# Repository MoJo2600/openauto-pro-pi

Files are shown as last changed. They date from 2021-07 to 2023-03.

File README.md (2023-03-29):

# Automotive power hat for OpenAuto

This hat is designed to work together with OpenAuto Pro and deliver some functionality which makes integrating OpenAuto into your car easier.

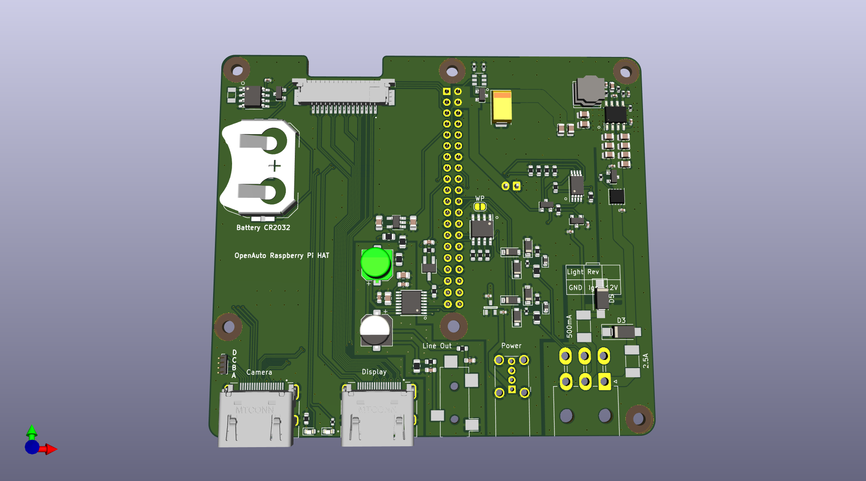
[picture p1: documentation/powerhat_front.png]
front


## Work in progress - a word of warning

I'm not an electronics professional and this board is currently work in progress. If somebody is willing to do a indepth review with me I would be very glad. Reach out to me on twitter [@MoJo2600](https://twitter.com/MoJo2600).

## Features

* Integrated 5A Power Supply
* Wide range power input (+7.5V to +40V)
* On-/Off circuit with ignition sensing
* 2 Digital inputs for e.g. reverse signal
* I2S sound
* RTC clock
* CSI to HDMI adapters to connect a display and camera
  * I2C bus availabe on the display connector for a light sensor
* Designed to fit exactly onto a [Geekworm x825](https://wiki.geekworm.com/index.php/X825) SSD V1 (Not tested with V2 but should fit)

## Connections
the following pins are used on the pi.

|Connection | Pin |
|---|-----|
|I2C |BCM23|
|I2C |BCM24|
|REVERSE |BCM8 |
|LIGHT |BCM25|
|PI UP |BCM23|
|SHUTDOWN |BCM24|
|I2S DAC MUTE |BCM16|
|I2S DAC BITCLK |BCM18|
|I2S DAC LRCLK  |BCM19|
|I2S DAC DATAIN |BCM21|

## OpenAuto Pro Setup

Set up the device before you add the header to the raspberry pi. The device will constantly reboot if the Start / Stop script is not installed. An alternative is to bridge the 3.3V pin from the raspberry pi to BCM23.

### Start / Stop script

Copy `scripts/startstop.sh` to the openauto device.

`sudo bash startstop.sh`

### I2C Real Time Clock

Make sure the battery has contact to the pad on the minus size. Mine had not and I added a little bit of solder to the pad to make contact.

```
# select pcf85063
```

### Rearview camera script

This script will open raspivid and show the picture of the rear camera.

Copy all files to the raspberry pi and start the setup

`./setup.sh`

### Brightness control script

My brightness script utilizes the TSL2561 ambient light sensor. The script implements a recommendation from analog devices
https://www.analog.com/en/design-notes/a-simple-implementation-of-lcd-brightness-control-using-the-max44009-ambientlight-sensor.html

Copy all files to the raspberry pi and start the setup

`./setup.sh`

### Audio output

The current audio circuit is not really usable. The output is very noisy und the signal is too low to usw it effectively. If you want to try i t you can use the following settings.

Add the overlays to `/boot/config.txt`

```
dtoverlay=hifiberry-dac
dtoverlay=i2s-mmap
```

After a reboot the sound should be working. Expect a line level output. If the volume is set to high, there will be clipping.

## Fixes for Issues

### Bluetooth Dongle BCM20702A1 not working

I had to install the bluetooth firmware for my broadcom bluetooth dongle from this repository https://github.com/winterheart/broadcom-bt-firmware.

The error in dmesg was:

```
bluetooth hci1: Direct firmware load for brcm/BCM20702A1-0a5c-21e8 failed with error -2
Bluetooth: hci1: BCM: Patch brcm/BCM20702A1-0a5c-21e8 not found
```

The installation was easy:

```
wget https://github.com/winterheart/broadcom-bt-firmware/raw/master/brcm/BCM20702A1-0a5c-21e8.hcd
sudo cp *.hcd /lib/firmware/brcm/
```

## History

Here is a picture of prototype V1 with a Mouseberry power supply.

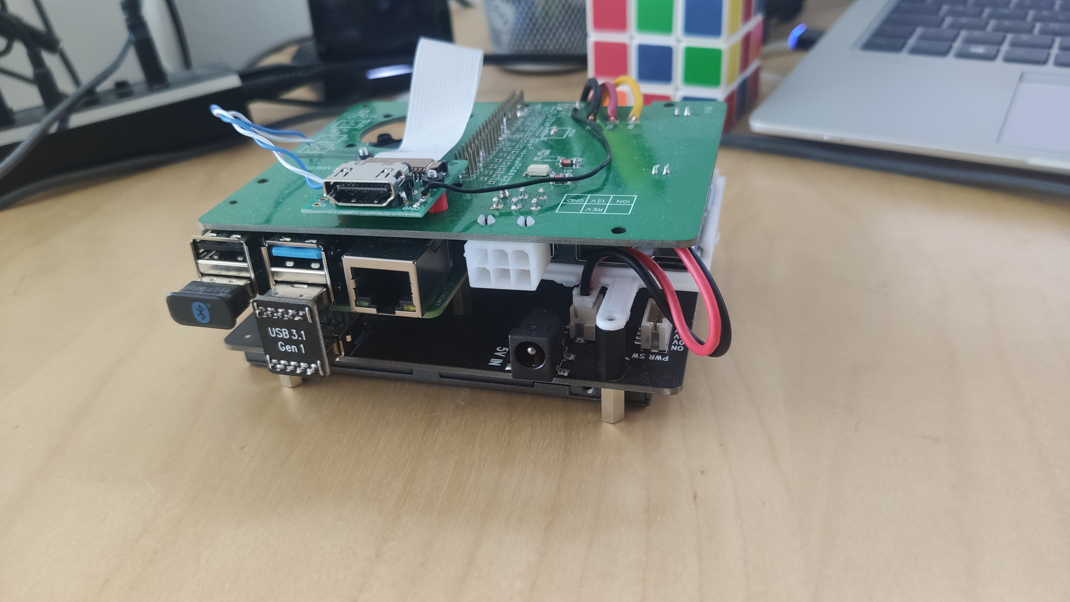
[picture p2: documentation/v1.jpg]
v1


## Disclaimer

Due to the fact we are not providing a product in the legal sense, we are also not providing any warranty in any aspect.

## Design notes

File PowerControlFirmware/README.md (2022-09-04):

# ATTINY firmware for power control

This firmeware controls the buck converter to power the PI. It waits for the PI to boot and signals the PI to shut down when the ignition is turned off.

## Pinout

## Implementation

## Flashing in WSL

Create udev rule for USBTiny to give regular users in `dialout` group rights to the device

```
echo 'SUBSYSTEM=="usb", ATTR{idProduct}=="0c9f", ATTR{idVendor}=="1781", MODE="0666", GROUP="dialout"' > /etc/udev/rules.d/99-USBTiny.rules
```

Restart the udev service

```
sudo service udev restart
sudo udevadm control --reload
```

Attach the USB device to the WSL

```
usbipd attach --bus-id X-Y
```

Flash your code

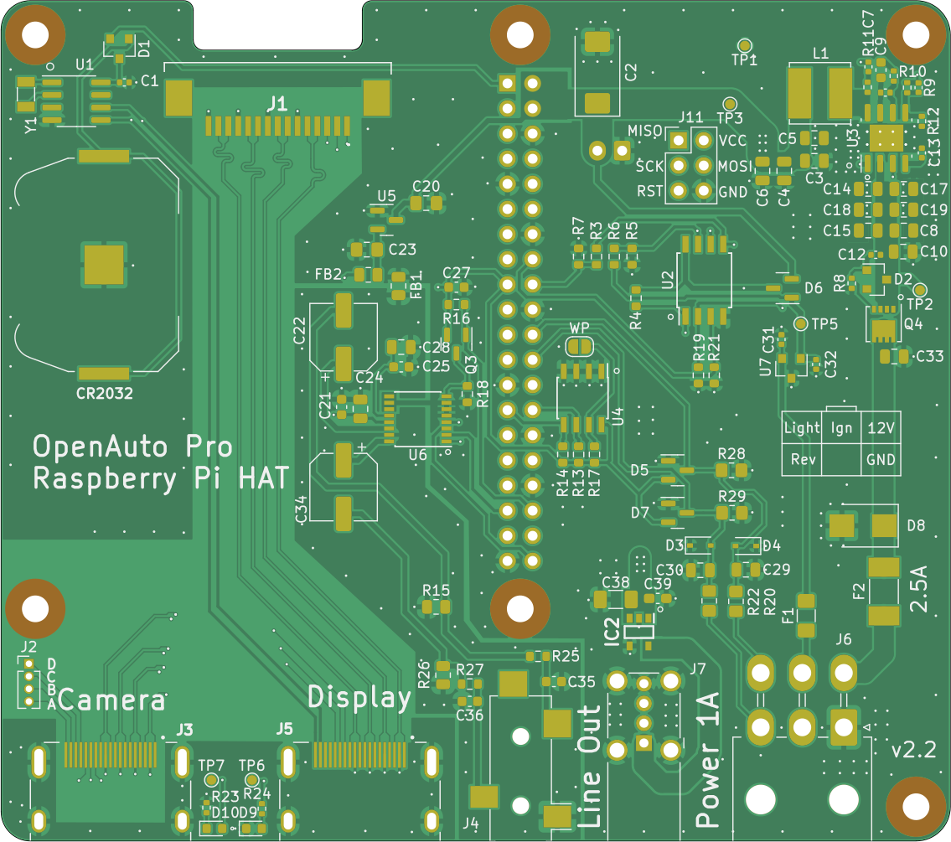
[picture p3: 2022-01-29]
CarPiPowerHat/foo.png

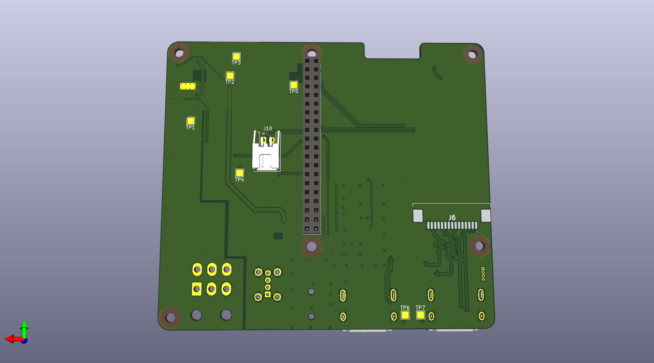
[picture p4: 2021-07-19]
documentation/powerhat_back.png

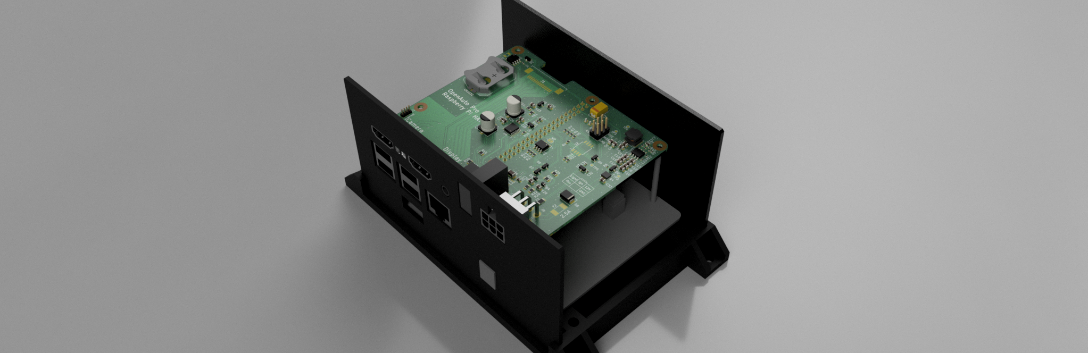
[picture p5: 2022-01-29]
CarPiPowerHat/prod/Raspberry Case V3 v27.png

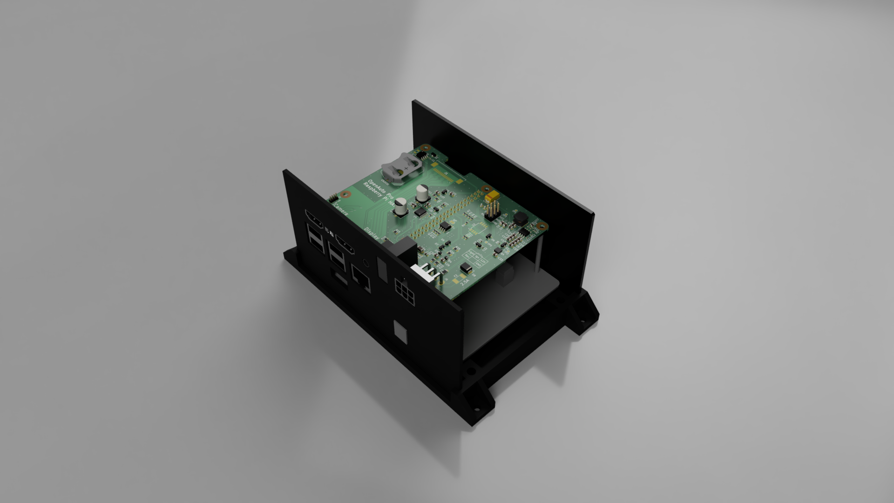
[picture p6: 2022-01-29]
CarPiPowerHat/prod/b1094724-6803-44ca-8cfa-f048102307d0.PNG

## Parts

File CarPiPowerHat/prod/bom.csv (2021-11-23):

Comment | Designator | Footprint | LCSC
1uF | C20,C23 | Capacitor_SMD:C_0805_2012Metric_Pad1.18x1.45mm_HandSolder | C28323
0.1uF | C21,C25,C27 | Capacitor_SMD:C_0603_1608Metric | C14663
47uF | C22,C34 | Capacitor_SMD:CP_Elec_6.3x7.7 | C164078
22nF | C29,C30 | Capacitor_SMD:C_0805_2012Metric | C1729
10uF | C3,C4,C5,C6,C24,C28 | Capacitor_SMD:C_0805_2012Metric | C15850
100n 100v | C33 | Capacitor_SMD:C_0805_2012Metric | C28233
0.01uF | C35,C36 | Capacitor_SMD:C_0603_1608Metric | C57112
100uF | C38 | Capacitor_SMD:C_1206_3216Metric_Pad1.33x1.80mm_HandSolder | C15008
1uF | C39 | Capacitor_SMD:C_0603_1608Metric_Pad1.08x0.95mm_HandSolder | C15849
100n 16v | C1,C7,C12,C13,C31,C32 | Capacitor_SMD:C_0402_1005Metric | C1525
10uF 35v | C8,C10,C14,C15,C17,C18,C19 | Capacitor_SMD:C_0805_2012Metric | C440198
1.2nF | C9 | Capacitor_SMD:C_0603_1608Metric | C30615
LED Green | D10 | LED_SMD:LED_0603_1608Metric | C72043
MMBZ5242BLT3G | D2 | Diode_SMD:D_SOT-23_ANK | C268585
PESD12VL1BA-N | D3,D4 | Diode_SMD:D_SOD-323 | C314261
BAT54S | D5,D7 | Package_TO_SOT_SMD:SOT-23 | C408389
BAT54C-7-F | D1,D6 | Package_TO_SOT_SMD:SOT-23 | C37704
SMBJ33A | D8 | Diode_SMD:D_SMB | C353366
LED Blue | D9 | LED_SMD:LED_0603_1608Metric | C72041
Fuse | F1 | Fuse:Fuse_1206_3216Metric_Pad1.42x1.75mm_HandSolder | C206984
Ferrite | FB1,FB2 | Resistor_SMD:R_0805_2012Metric | C1017
BD2226G-TR | IC2 | SamacSys_Parts:SOT95P280X125-5N | C308587
DMG2305 | Q3 | Package_TO_SOT_SMD:SOT-23 | C144153
DMP3013SFV-7 | Q4 | Package_SON:Diodes_PowerDI3333-8 | C264098
20K 1% | R10 | Resistor_SMD:R_0402_1005Metric | C25765
10R | R11 | Resistor_SMD:R_0402_1005Metric | C25077
2.2K 1% | R12 | Resistor_SMD:R_0402_1005Metric | C25879
3.9K | R13,R14 | Resistor_SMD:R_0603_1608Metric | C23018
220k | R15,R26 | Resistor_SMD:R_0805_2012Metric | C17521
10K | R16,R17,R18 | Resistor_SMD:R_0603_1608Metric | C25804
10k | R20,R22 | Resistor_SMD:R_0805_2012Metric_Pad1.20x1.40mm_HandSolder | C17414
200 1% | R23,R24 | Resistor_SMD:R_0402_1005Metric | C25087
100 | R25,R27 | Resistor_SMD:R_0603_1608Metric | C22775
1M | R28,R29 | Resistor_SMD:R_0805_2012Metric_Pad1.20x1.40mm_HandSolder | C17514
10K 1% | R3,R4,R5,R7,R19,R21 | Resistor_SMD:R_0603_1608Metric | C25804
3.3K 1% | R6 | Resistor_SMD:R_0603_1608Metric | C22978
12K 1% | R8,R9 | Resistor_SMD:R_0402_1005Metric | C25752
PCF85063AT/AAZ | U1 | Package_SO:SOIC-8_3.9x4.9mm_P1.27mm | C7440
ATtiny45V-20SU | U2 | Package_SO:SOIC-8W_5.3x5.3mm_P1.27mm | C62689
AP64501SP-13 | U3 | Package_SO:SOIC-8-1EP_3.9x4.9mm_P1.27mm_EP2.95x4.9mm_Mask2.71x3.4mm_ThermalVias | C2071517
CAT24C32 | U4 | Package_SOIC:SOIC-8_3.9x4.9mm_P1.27mm | C81193
XC6206P332MR | U5 | Package_TO_SOT_SMD:SOT-23 | C5446
UDA1334ATS | U6 | Package_SO:SSOP-16_4.4x5.2mm_P0.65mm | C494494
LM3480-5.0 | U7 | Package_TO_SOT_SMD:SOT-23 | C129960
FC-12M32.768KHZ7PF20PPM | Y1 | Crystal:Crystal_SMD_3215-2Pin_3.2x1.5mm | C99009

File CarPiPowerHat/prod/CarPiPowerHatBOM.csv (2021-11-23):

Comment | Designator | Footprint | LCSC
Battery_Cell | BT1 | Battery:BatteryHolder_Keystone_3034_1x20mm
nf | C11,C16 | Capacitor_SMD:C_0402_1005Metric
100uF | C2 | Capacitor_Tantalum_SMD:CP_EIA-7343-31_Kemet-D
1uF | C20,C23 | Capacitor_SMD:C_0805_2012Metric_Pad1.18x1.45mm_HandSolder | C28323
0.1uF | C21,C25,C27 | Capacitor_SMD:C_0603_1608Metric | C14663
47uF | C22,C34 | Capacitor_SMD:CP_Elec_6.3x7.7 | C164078
22nF | C29,C30 | Capacitor_SMD:C_0805_2012Metric | C1729
10uF | C3,C4,C5,C6,C24,C28 | Capacitor_SMD:C_0805_2012Metric | C15850
100n 100v | C33 | Capacitor_SMD:C_0805_2012Metric | C28233
0.01uF | C35,C36 | Capacitor_SMD:C_0603_1608Metric | C57112
100uF | C38 | Capacitor_SMD:C_1206_3216Metric_Pad1.33x1.80mm_HandSolder | C15008
1uF | C39 | Capacitor_SMD:C_0603_1608Metric_Pad1.08x0.95mm_HandSolder | C15849
100n 16v | C1,C7,C12,C13,C31,C32 | Capacitor_SMD:C_0402_1005Metric | C1525
10uF 35v | C8,C10,C14,C15,C17,C18,C19 | Capacitor_SMD:C_0805_2012Metric | C440198
1.2nF | C9 | Capacitor_SMD:C_0603_1608Metric | C30615
LED Green | D10 | LED_SMD:LED_0603_1608Metric | C72043
MMBZ5242BLT3G | D2 | Diode_SMD:D_SOT-23_ANK | C268585
PESD12VL1BA-N | D3,D4 | Diode_SMD:D_SOD-323 | C314261
BAT54S | D5,D7 | Package_TO_SOT_SMD:SOT-23 | C408389
BAT54C-7-F | D1,D6 | Package_TO_SOT_SMD:SOT-23 | C37704
SMBJ33A | D8 | Diode_SMD:D_SMB | C353366
LED Blue | D9 | LED_SMD:LED_0603_1608Metric | C72041
Fuse | F1 | Fuse:Fuse_1206_3216Metric_Pad1.42x1.75mm_HandSolder | C206984
Fuse | F2 | Fuse:Fuse_Littelfuse-NANO2-451_453
Ferrite | FB1,FB2 | Resistor_SMD:R_0805_2012Metric | C1017
3mm_Mounting_Hole | H1,H2,H3,H4,H5,H6 | MountingHole:MountingHole_2.7mm_M2.5
BD2226G-TR | IC2 | SamacSys_Parts:SOT95P280X125-5N | C308587
1-84953-5 | J1,J10 | SamacSys_Parts:1849535
Conn_01x06_Male | J11 | Connector_PinHeader_2.54mm:PinHeader_2x03_P2.54mm_Vertical
Conn_01x04 | J2 | Connector_PinHeader_2.00mm:PinHeader_1x04_P2.00mm_Vertical
HDMI_A_1.4 | J3,J5 | project_footprints:EDAC 690-019-298-412
AudioJack2_Ground | J4 | Connector_Audio:Jack_3.5mm_CUI_SJ-3524-SMT_Horizontal
Conn_02x03_Counter_Clockwise | J6 | Connector_Molex:Molex_Mini-Fit_Jr_5569-06A2_2x03_P4.20mm_Horizontal
USB_A | J7 | Connector_USB:USB_A_Wuerth_614004134726_Horizontal
Conn_01x02_Male | J8 | Connector_JST:JST_XH_S2B-XH-A_1x02_P2.50mm_Horizontal
40HAT | J9 | Connector_PinSocket_2.54mm:PinSocket_2x20_P2.54mm_Vertical
SolderJumper_2_Open | JP1 | Jumper:SolderJumper-2_P1.3mm_Open_RoundedPad1.0x1.5mm
SRN6045TA-3R3Y | L1 | Inductor_SMD:L_Bourns_SRN6045TA
DMG2305 | Q3 | Package_TO_SOT_SMD:SOT-23 | C144153
DMP3013SFV-7 | Q4 | Package_SON:Diodes_PowerDI3333-8 | C264098
20K 1% | R10 | Resistor_SMD:R_0402_1005Metric | C25765
10R | R11 | Resistor_SMD:R_0402_1005Metric | C25077
2.2K 1% | R12 | Resistor_SMD:R_0402_1005Metric | C25879
3.9K | R13,R14 | Resistor_SMD:R_0603_1608Metric | C23018
220k | R15,R26 | Resistor_SMD:R_0805_2012Metric | C17521
10K | R16,R17,R18 | Resistor_SMD:R_0603_1608Metric | C25804
10k | R20,R22 | Resistor_SMD:R_0805_2012Metric_Pad1.20x1.40mm_HandSolder | C17414
200 1% | R23,R24 | Resistor_SMD:R_0402_1005Metric | C25087
100 | R25,R27 | Resistor_SMD:R_0603_1608Metric | C22775
1M | R28,R29 | Resistor_SMD:R_0805_2012Metric_Pad1.20x1.40mm_HandSolder | C17514
10K 1% | R3,R4,R5,R7,R19,R21 | Resistor_SMD:R_0603_1608Metric | C25804
3.3K 1% | R6 | Resistor_SMD:R_0603_1608Metric | C22978
12K 1% | R8,R9 | Resistor_SMD:R_0402_1005Metric | C25752
TestPoint | TP1,TP2,TP3,TP5,TP6,TP7 | TestPoint:TestPoint_Pad_D1.0mm
PCF85063AT/AAZ | U1 | Package_SO:SOIC-8_3.9x4.9mm_P1.27mm | C7440
ATtiny45V-20SU | U2 | Package_SO:SOIC-8W_5.3x5.3mm_P1.27mm | C62689
AP64501SP-13 | U3 | Package_SO:SOIC-8-1EP_3.9x4.9mm_P1.27mm_EP2.95x4.9mm_Mask2.71x3.4mm_ThermalVias | C2071517
CAT24C32 | U4 | Package_SOIC:SOIC-8_3.9x4.9mm_P1.27mm | C81193
XC6206P332MR | U5 | Package_TO_SOT_SMD:SOT-23 | C5446
UDA1334ATS | U6 | Package_SO:SSOP-16_4.4x5.2mm_P0.65mm | C494494
LM3480-5.0 | U7 | Package_TO_SOT_SMD:SOT-23 | C129960
FC-12M32.768KHZ7PF20PPM | Y1 | Crystal:Crystal_SMD_3215-2Pin_3.2x1.5mm | C99009

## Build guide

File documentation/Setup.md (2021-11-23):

# Initial Setup

!Do not power the Raspberry Pi from the USB-C port once you have the SSD attached
!Do not power the Raspberry Pi from the USB-C port when the HAT is attached

Before we attach the header we have to setup the

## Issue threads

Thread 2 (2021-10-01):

I2C decoder with UDA1334ATS is obsolete

MoJo2600, 2021-10-01:
The chip UDA1334ATS is not produced anymore, what I did not realize. So the audio circuit is obsolete. I don't know what a good replacement would be - Maybe WM8960 but this chip is not available on JLCPCB and hard to hand solder.

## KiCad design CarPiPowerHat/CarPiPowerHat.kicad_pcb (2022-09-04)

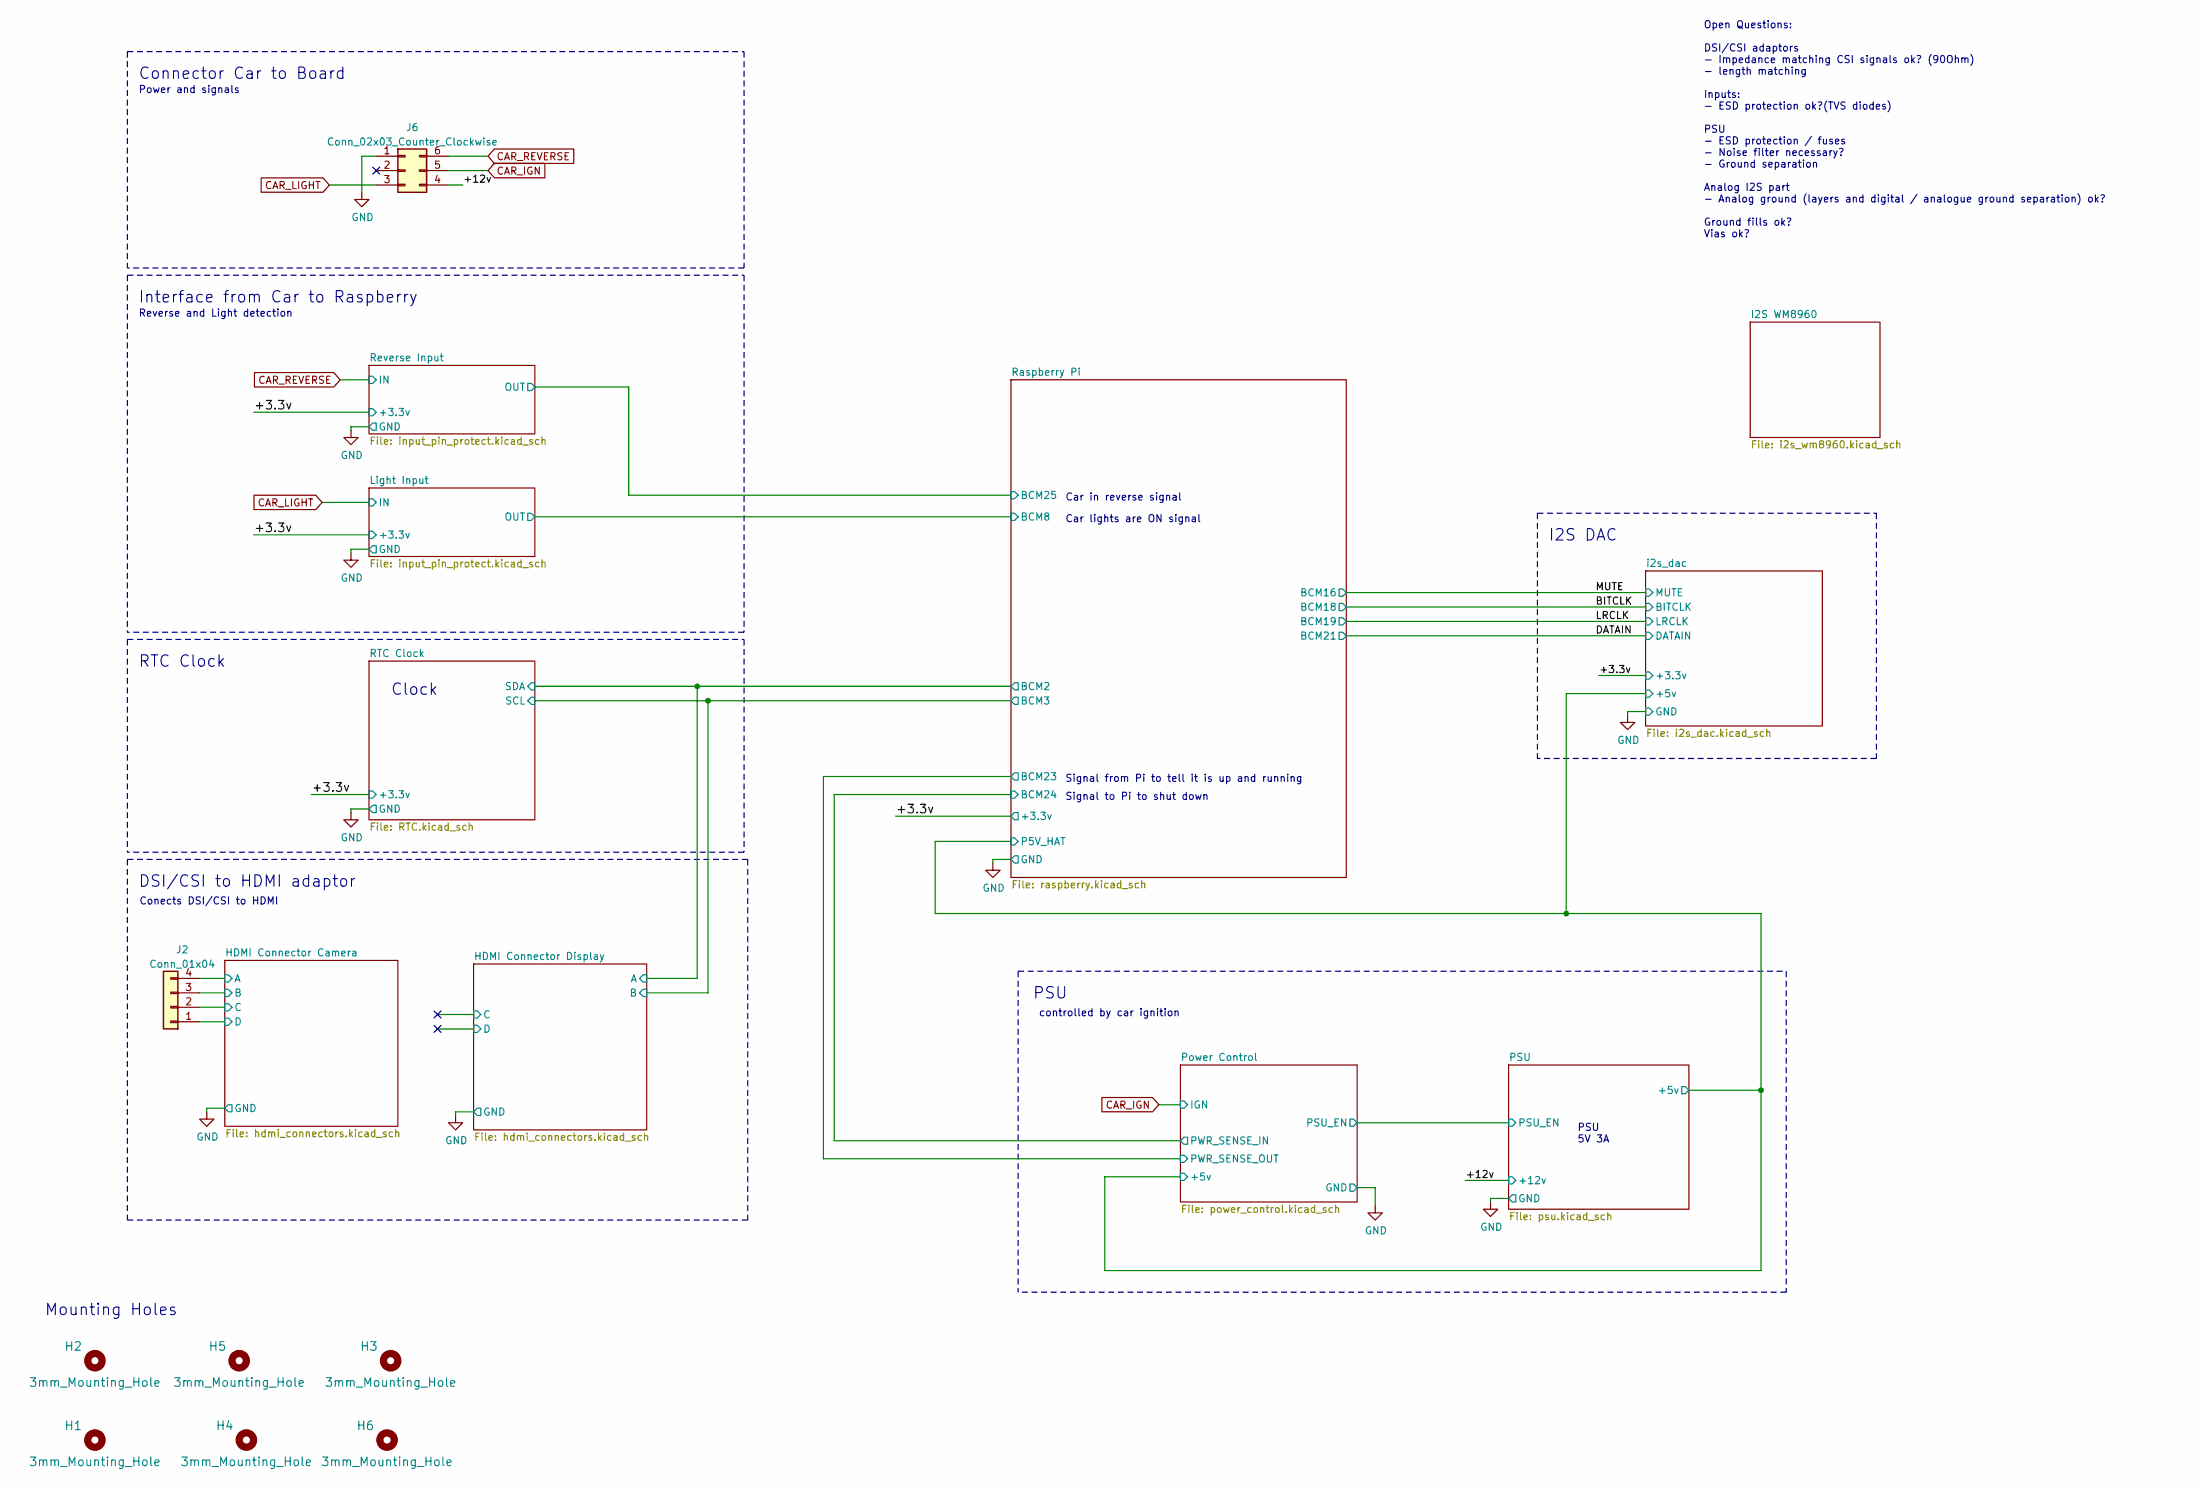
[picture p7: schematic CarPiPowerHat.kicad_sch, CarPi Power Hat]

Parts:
H1, H2, H3, H4, H5, H6: 3mm_Mounting_Hole; MountingHole_2.7mm_M2.5
J2: Conn_01x04; PinHeader_1x04_P2.00mm_Vertical
J6: Conn_02x03_Counter_Clockwise; Molex_Mini-Fit_Jr_5569-06A2_2x03_P4.20mm_Horizontal; MouserNr 538-50-36-1798

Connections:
/+12v: J6.4; also elsewhere on the board
/HDMI Connector Camera/A: J2.4; also elsewhere on the board
/HDMI Connector Camera/B: J2.3; also elsewhere on the board
/HDMI Connector Camera/C: J2.2; also elsewhere on the board
/HDMI Connector Camera/D: J2.1; also elsewhere on the board
CAR_IGN: J6.5; also elsewhere on the board
CAR_LIGHT: J6.3; also elsewhere on the board
CAR_REVERSE: J6.6; also elsewhere on the board
GND: J6.1; also elsewhere on the board

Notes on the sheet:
Open Questions: DSI/CSI adaptors - Impedance matching CSI signals ok? (90Ohm) - length matching Inputs: - ESD protection ok?(TVS diodes) PSU - ESD protection / fuses - Noise filter necessary? - Ground separation Analog I2S part - Analog ground (layers and digital / analogue ground separation) ok? G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
PSU 5V 3A
Mounting Holes
Power and signals
PSU
I2S DAC
RTC Clock
controlled by car ignition
Clock
Signal to Pi to shut down
Signal from Pi to tell it is up and running
Car lights are ON signal
Connector Car to Board
DSI/CSI to HDMI adaptor
Reverse and Light detection
Conects DSI/CSI to HDMI
Car in reverse signal
Interface from Car to Raspberry

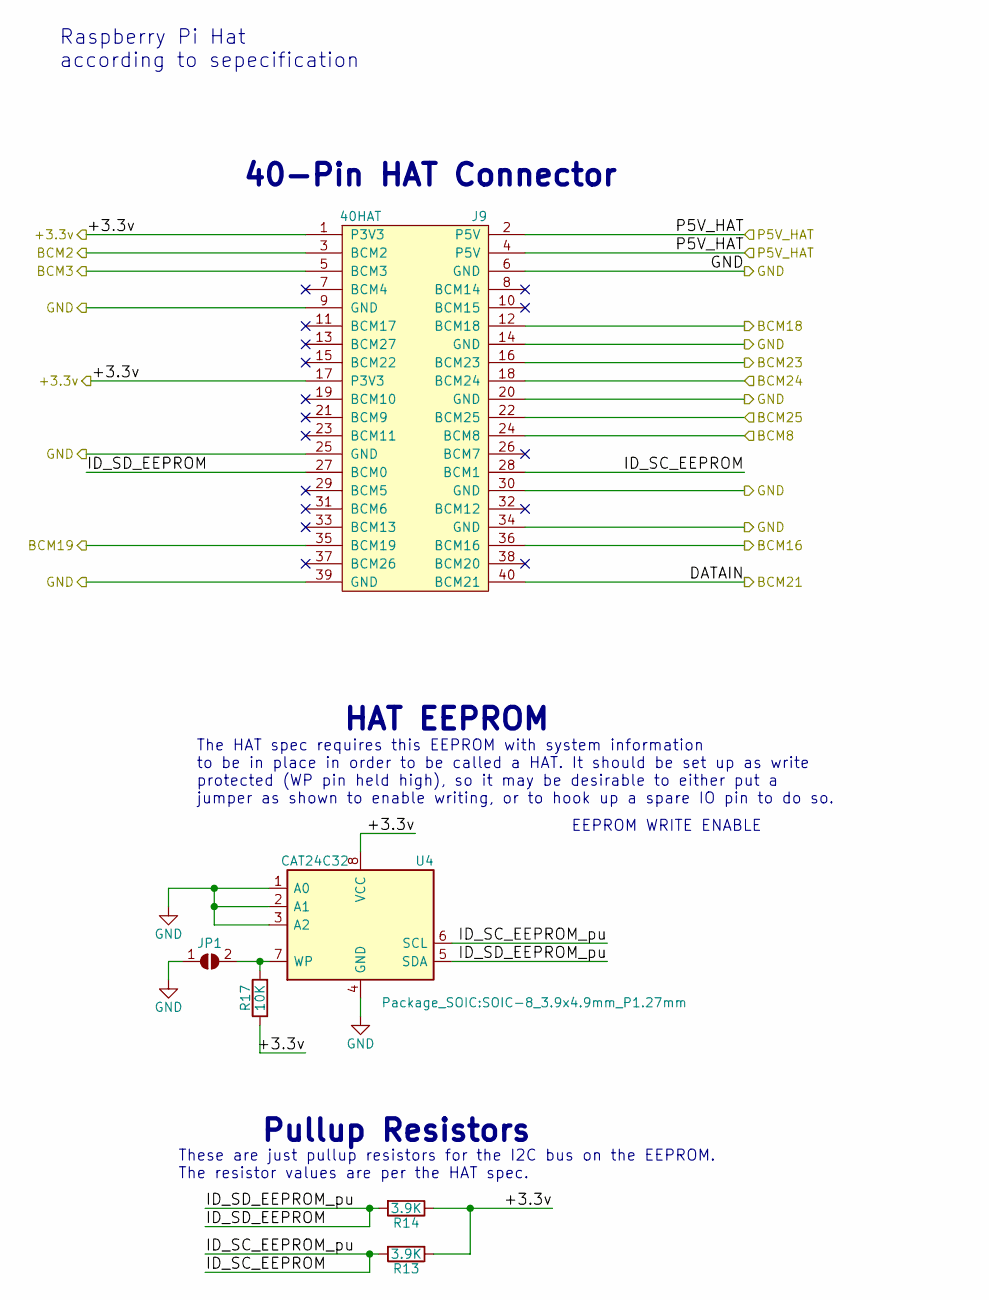
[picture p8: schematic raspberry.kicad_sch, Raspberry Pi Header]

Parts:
J9: 40HAT; PinSocket_2x20_P2.54mm_Vertical
JP1: SolderJumper_2_Open; SolderJumper-2_P1.3mm_Open_RoundedPad1.0x1.5mm
R13, R14: 3.9K; R_0603_1608Metric; LCSC C23018
R17: 10K; R_0603_1608Metric; LCSC C25804
U4: CAT24C32; SOIC-8_3.9x4.9mm_P1.27mm; LCSC C81193

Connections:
/+3.3v: J9.1 (P3V3), J9.17 (P3V3), R13.1, R14.1, R17.1, U4.8 (VCC); also elsewhere on the board
/BITCLK: J9.12 (BCM18); also elsewhere on the board
/DATAIN: J9.40 (BCM21); also elsewhere on the board
/LRCLK: J9.35 (BCM19); also elsewhere on the board
/Light Input/OUT: J9.24 (BCM8); also elsewhere on the board
/MUTE: J9.36 (BCM16); also elsewhere on the board
/Power Control/PWR_SENSE_IN: J9.18 (BCM24); also elsewhere on the board
/RTC Clock/SCL: J9.5 (BCM3); also elsewhere on the board
/RTC Clock/SDA: J9.3 (BCM2); also elsewhere on the board
/Raspberry Pi/BCM25: J9.22 (BCM25); also elsewhere on the board
/Raspberry Pi/ID_SC_EEPROM: J9.28 (BCM1), R13.2, U4.6 (SCL)
/Raspberry Pi/ID_SD_EEPROM: J9.27 (BCM0), R14.2, U4.5 (SDA)
/Raspberry Pi/P5V_HAT: J9.2 (P5V), J9.4 (P5V); also elsewhere on the board
GND: J9.6 (GND), J9.9 (GND), J9.14 (GND), J9.20 (GND), J9.25 (GND), J9.30 (GND), J9.34 (GND), J9.39 (GND), JP1.1 (A), U4.1 (A0), U4.2 (A1), U4.3 (A2), U4.4 (GND); also elsewhere on the board
unnamed: JP1.2 (B), R17.2, U4.7 (WP)
PWR_SENSE_OUT: J9.16 (BCM23); also elsewhere on the board

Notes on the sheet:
EEPROM WRITE ENABLE
Pullup Resistors
40-Pin HAT Connector
HAT EEPROM
The HAT spec requires this EEPROM with system information to be in place in order to be called a HAT. It should be set up as write protected (WP pin held high), so it may be desirable to either put a jumper as shown to enable writing, or to hook up a spare IO pin to do so.
Raspberry Pi Hat according to sepecification
These are just pullup resistors for the I2C bus on the EEPROM. The resistor values are per the HAT spec.

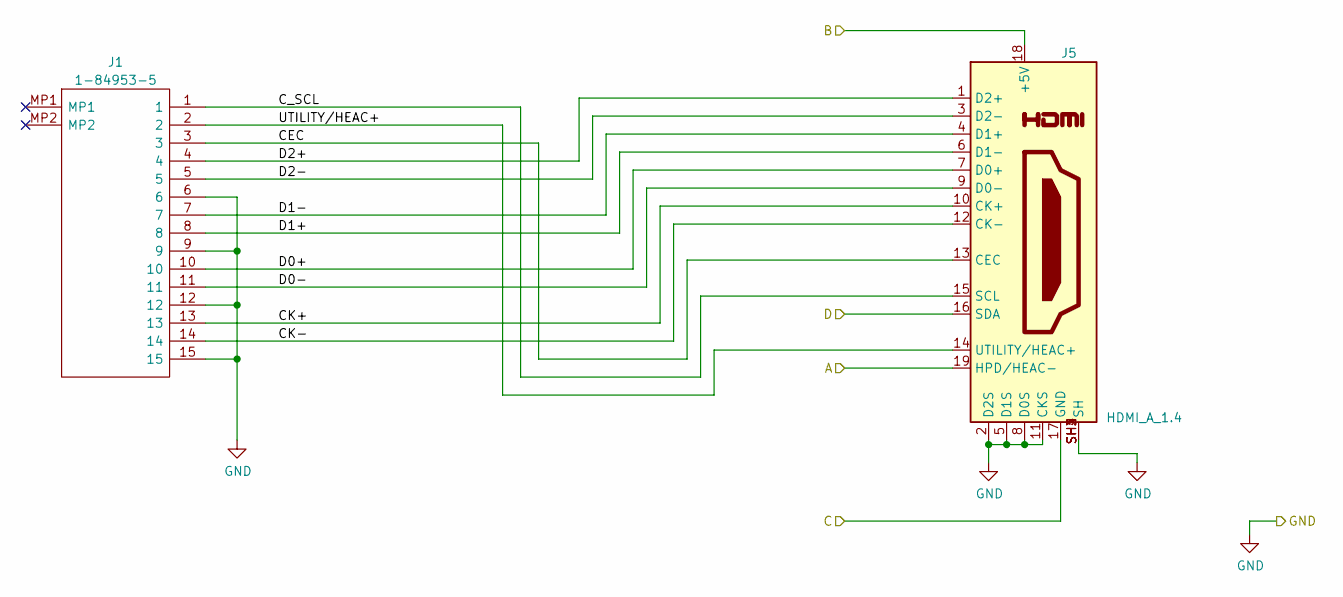
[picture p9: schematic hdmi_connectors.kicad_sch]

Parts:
J1: 1-84953-5; 1849535; Manufacturer_Part_Number 1-84953-5; Mouser Part Number 571-1-84953-5
J5: HDMI_A_1.4; EDAC 690-019-298-412; Part Description HDMI Connector, Right Angle, 19 Contact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

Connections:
/HDMI Connector Display/C: J5.17 (GND)
/HDMI Connector Display/CEC: J1.3, J5.13 (CEC)
/HDMI Connector Display/CK+: J1.13, J5.10 (CK+)
/HDMI Connector Display/CK-: J1.14, J5.12 (CK-)
/HDMI Connector Display/C_SCL: J1.1, J5.15 (SCL)
/HDMI Connector Display/D: J5.16 (SDA)
/HDMI Connector Display/D0+: J1.10, J5.7 (D0+)
/HDMI Connector Display/D0-: J1.11, J5.9 (D0-)
/HDMI Connector Display/D1+: J1.8, J5.6 (D1-)
/HDMI Connector Display/D1-: J1.7, J5.4 (D1+)
/HDMI Connector Display/D2+: J1.4, J5.1 (D2+)
/HDMI Connector Display/D2-: J1.5, J5.3 (D2-)
/HDMI Connector Display/UTILITY/HEAC+: J1.2, J5.14 (UTILITY/HEAC+)
/RTC Clock/SCL: J5.18 (+5V); also elsewhere on the board
/RTC Clock/SDA: J5.19 (HPD/HEAC-); also elsewhere on the board
GND: J1.6, J1.9, J1.12, J1.15, J5.2 (D2S), J5.5 (D1S), J5.8 (D0S), J5.11 (CKS), J5.SH1 (SH), J5.SH2 (SH), J5.SH3 (SH), J5.SH4 (SH); also elsewhere on the board

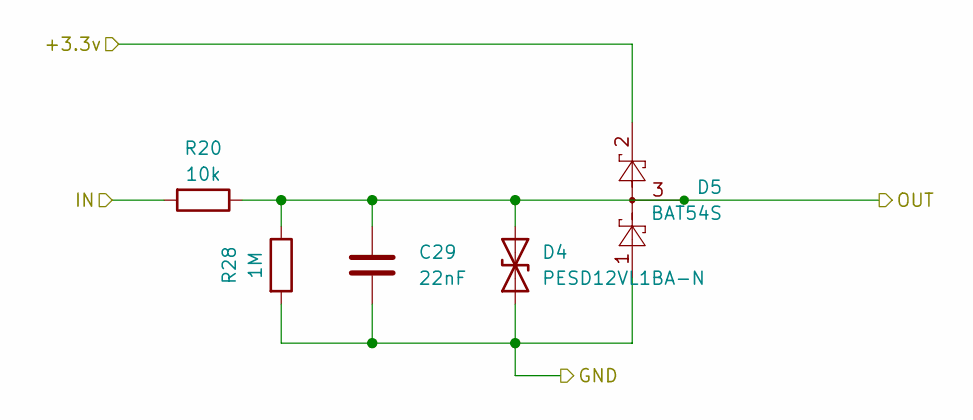
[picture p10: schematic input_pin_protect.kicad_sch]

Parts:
C29: 22nF; C_0805_2012Metric; LCSC C1729
D4: PESD12VL1BA-N; D_SOD-323; LCSC C314261
D5: BAT54S; SOT-23; LCSC C408389
R20: 10k; R_0805_2012Metric_Pad1.20x1.40mm_HandSolder; LCSC C17414
R28: 1M; R_0805_2012Metric_Pad1.20x1.40mm_HandSolder; LCSC C17514

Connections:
/+3.3v: D5.2; also elsewhere on the board
/Raspberry Pi/BCM25: C29.1, D4.2 (A2), D5.3, R20.1, R28.1; also elsewhere on the board
CAR_REVERSE: R20.2; also elsewhere on the board
GND: C29.2, D4.1 (A1), D5.1, R28.2; also elsewhere on the board

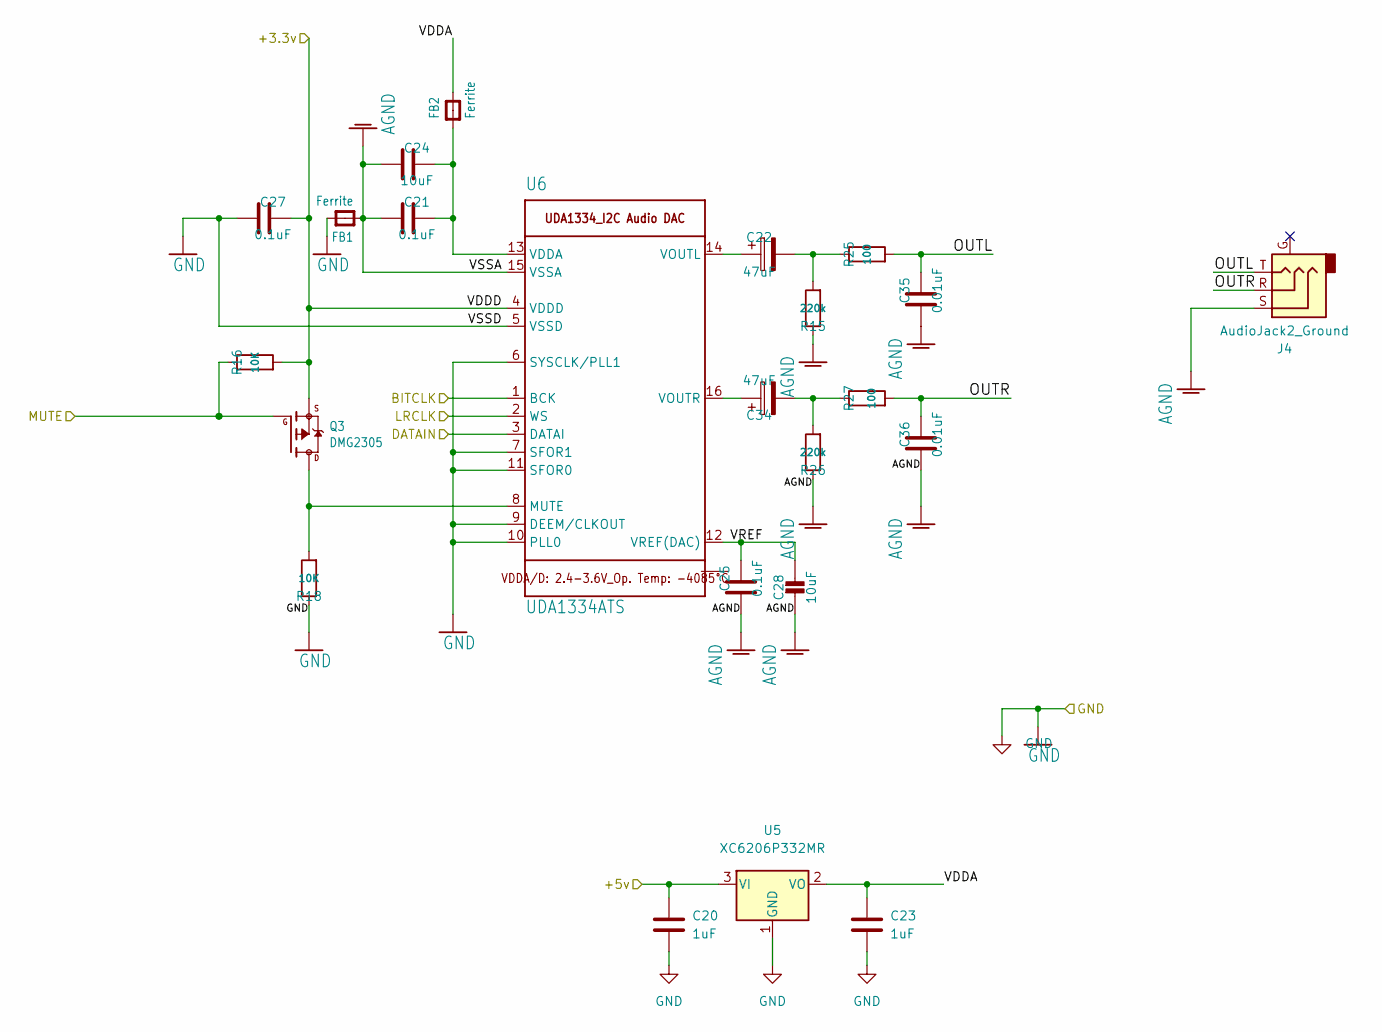
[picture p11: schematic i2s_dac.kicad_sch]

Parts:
C20, C23: 1uF; C_0805_2012Metric_Pad1.18x1.45mm_HandSolder; LCSC C28323
C21, C25, C27: 0.1uF; C_0603_1608Metric; LCSC C14663
C22, C34: 47uF; CP_Elec_6.3x7.7; LCSC C164078
C24, C28: 10uF; C_0805_2012Metric; LCSC C15850
C35, C36: 0.01uF; C_0603_1608Metric; LCSC C57112
FB1, FB2: Ferrite; R_0805_2012Metric; LCSC C1017
J4: AudioJack2_Ground; Jack_3.5mm_CUI_SJ-3524-SMT_Horizontal; Mouser 490-SJ3524-SMT-TR-GR
Q3: DMG2305; SOT-23; LCSC C144153
R15, R26: 220k; R_0805_2012Metric; LCSC C17521
R16, R18: 10K; R_0603_1608Metric; LCSC C25804
R25, R27: 100; R_0603_1608Metric; LCSC C22775
U5: XC6206P332MR; SOT-23; LCSC C5446
U6: UDA1334ATS; SSOP-16_4.4x5.2mm_P0.65mm; LCSC C494494

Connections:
/+3.3v: C27.1, Q3.2 (S), R16.2, U6.4 (VDDD); also elsewhere on the board
/BITCLK: U6.1 (BCK); also elsewhere on the board
/DATAIN: U6.3 (DATAI); also elsewhere on the board
/LRCLK: U6.2 (WS); also elsewhere on the board
/MUTE: Q3.1 (G), R16.1; also elsewhere on the board
/Raspberry Pi/P5V_HAT: C20.1, U5.3 (VI); also elsewhere on the board
/i2s_dac/OUTL: C35.1, J4.T, R25.2
/i2s_dac/OUTR: C36.1, J4.R, R27.2
/i2s_dac/VDDA: C23.1, FB2.2, U5.2 (VO)
/i2s_dac/VREF: C25.1, C28.1, U6.12 (VREF(DAC))
AGND: C21.2, C24.2, C25.2, C28.2, C35.2, C36.2, FB1.1, J4.S, R15.1, R26.1, U6.15 (VSSA)
GND: C20.2, C23.2, C27.2, FB1.2, R18.1, U5.1 (GND), U6.5 (VSSD), U6.6 (SYSCLK/PLL1), U6.7 (SFOR1), U6.9 (DEEM/CLKOUT), U6.10 (PLL0), U6.11 (SFOR0); also elsewhere on the board
unnamed: C21.1, C24.1, FB2.1, U6.13 (VDDA)
unnamed: C22.1, U6.14 (VOUTL)
unnamed: C22.2, R15.2, R25.1
unnamed: C34.1, U6.16 (VOUTR)
unnamed: C34.2, R26.2, R27.1
unnamed: Q3.3 (D), R18.2, U6.8 (MUTE)

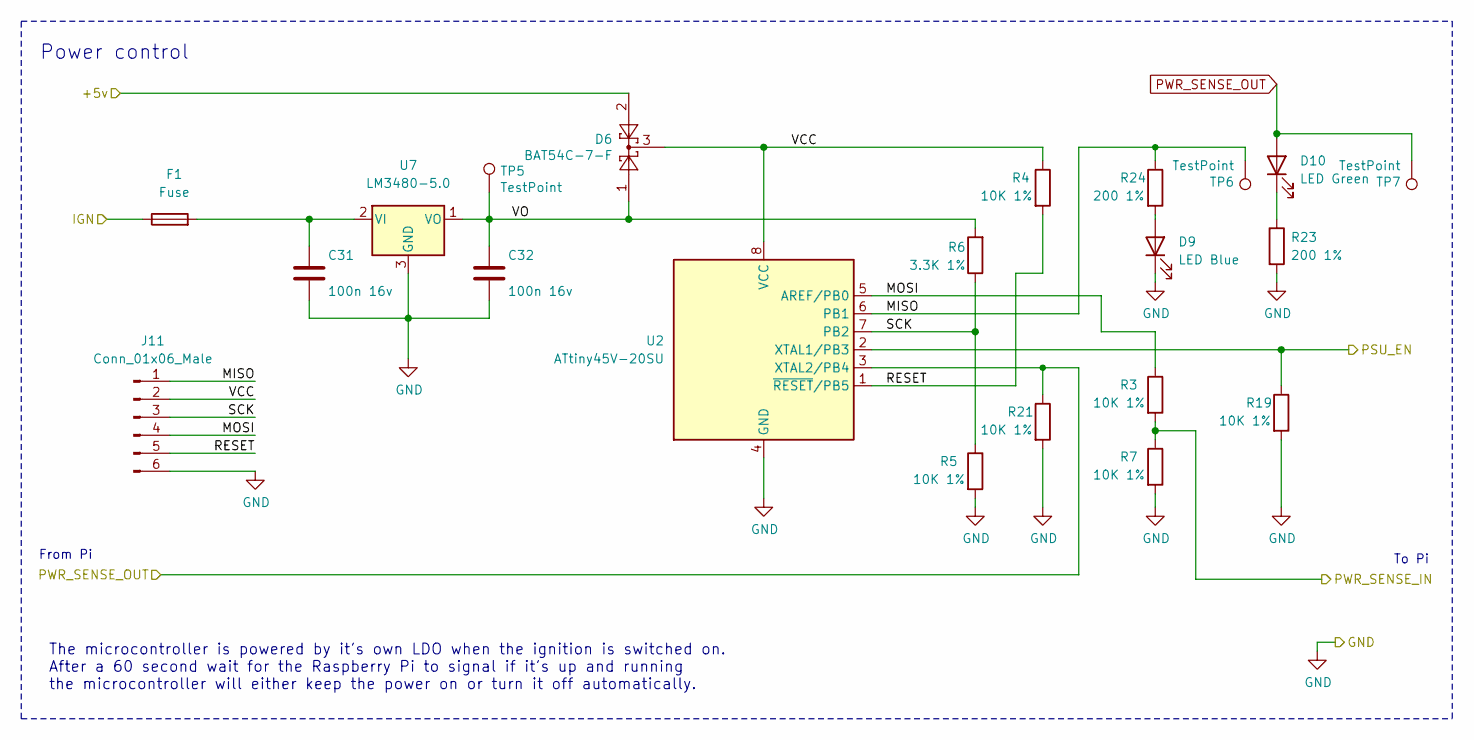
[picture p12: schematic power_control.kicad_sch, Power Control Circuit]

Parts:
C31, C32: 100n 16v; C_0402_1005Metric; Part Description 0.1uF 10% 16V Ceramic Capacitor X7R 040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; LCSC C1525
D6: BAT54C-7-F; SOT-23; Part Description Diode Array 1 Pair Common Cathode Schot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; LCSC C37704
D9: LED Blue; LED_0603_1608Metric; LCSC C72041
D10: LED Green; LED_0603_1608Metric; LCSC C72043
F1: Fuse; Fuse_1206_3216Metric_Pad1.42x1.75mm_HandSolder; LCSC C206984
J11: Conn_01x06_Male; PinHeader_2x03_P2.54mm_Vertical
R3, R4, R5, R7, R19, R21: 10K 1%; R_0603_1608Metric; Part Description Resistor 12K M1005 1% 63mW; LCSC C25804
R6: 3.3K 1%; R_0603_1608Metric; Part Description Resistor 12K M1005 1% 63mW; LCSC C22978
R23: 200 1%; R_0402_1005Metric; LCSC C25087
R24: 200 1%; R_0402_1005Metric; Part Description Resistor 12K M1005 1% 63mW; LCSC C25087
TP5, TP6, TP7: TestPoint; TestPoint_Pad_D1.0mm
U2: ATtiny45V-20SU; SOIC-8W_5.3x5.3mm_P1.27mm; LCSC C62689
U7: LM3480-5.0; SOT-23; LCSC C129960

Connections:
/PSU/PSU_EN: R19.1, U2.2 (XTAL1/PB3); also elsewhere on the board
/Power Control/MISO: J11.1, R24.1, TP6.1, U2.6 (PB1)
/Power Control/MOSI: J11.4, R3.1, U2.5 (AREF/PB0)
/Power Control/PWR_SENSE_IN: R3.2, R7.1; also elsewhere on the board
/Power Control/RESET: J11.5, R4.2, U2.1 (~RESET/PB5)
/Power Control/SCK: J11.3, R5.1, R6.1, U2.7 (PB2)
/Power Control/VCC: D6.3, J11.2, R4.1, U2.8 (VCC)
/Power Control/VO: C32.1, D6.1, R6.2, TP5.1, U7.1 (VO)
/Raspberry Pi/P5V_HAT: D6.2; also elsewhere on the board
CAR_IGN: F1.1; also elsewhere on the board
GND: C31.2, C32.2, D9.1 (K), J11.6, R5.2, R7.2, R19.2, R21.2, R23.2, U2.4 (GND), U7.3 (GND); also elsewhere on the board
unnamed: C31.1, F1.2, U7.2 (VI)
unnamed: D9.2 (A), R24.2
unnamed: D10.1 (K), R23.1
PWR_SENSE_OUT: D10.2 (A), R21.1, TP7.1, U2.3 (XTAL2/PB4); also elsewhere on the board

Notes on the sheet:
Power control
The microcontroller is powered by it's own LDO when the ignition is switched on. After a 60 second wait for the Raspberry Pi to signal if it's up and running the microcontroller will either keep the power on or turn it off automatically.
From Pi
To Pi

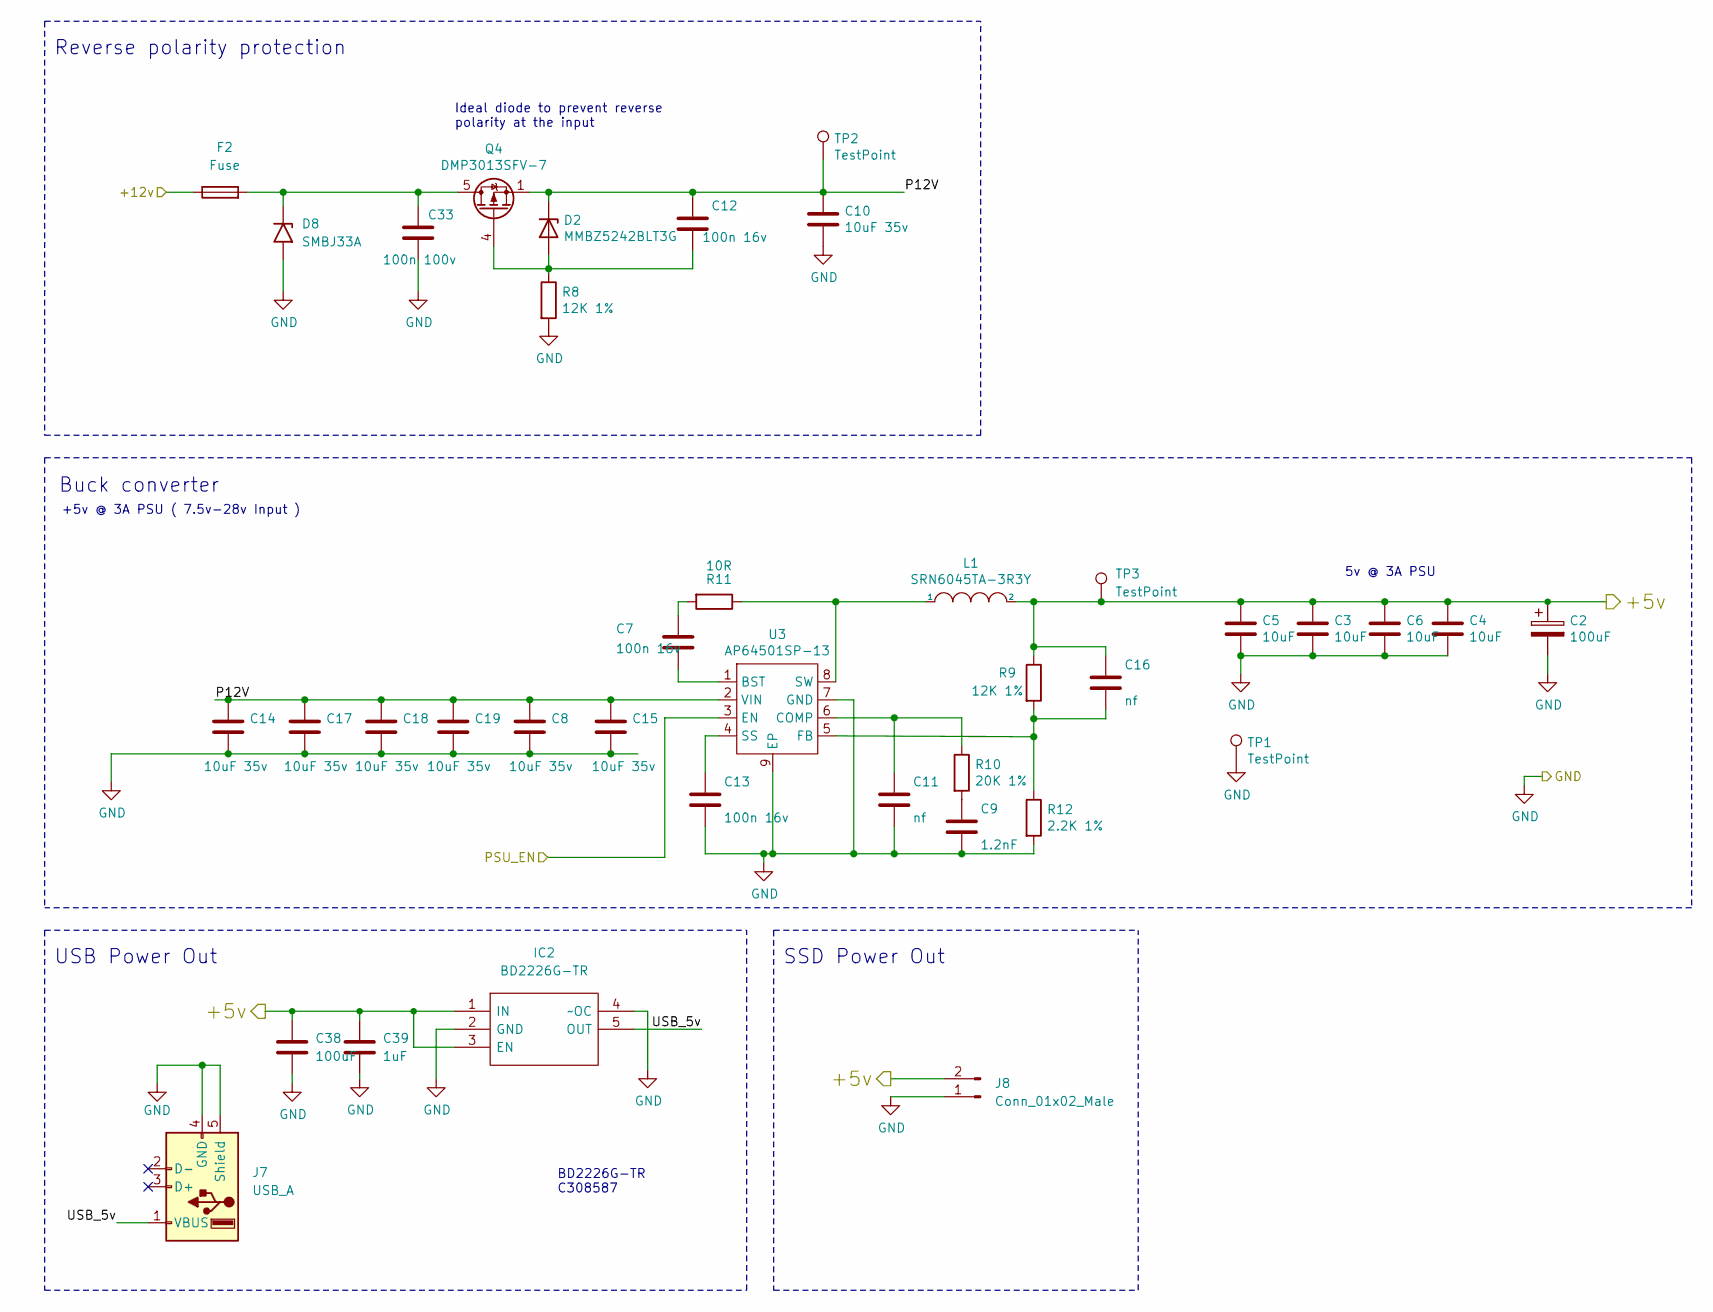
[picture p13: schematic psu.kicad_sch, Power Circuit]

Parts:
C2: 100uF; CP_EIA-7343-31_Kemet-D; Part Description Capacitor, SP-Cap, 100u, 6.3V, 15mR ESR
C3, C4, C5, C6: 10uF; C_0805_2012Metric; Part Description 10uF 10% 10V Ceramic Capacitor X7R 0805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; LCSC C15850
C7, C12, C13: 100n 16v; C_0402_1005Metric; Part Description 0.1uF 10% 16V Ceramic Capacitor X7R 040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; LCSC C1525
C8, C10, C14, C15, C17, C18, C19: 10uF 35v; C_0805_2012Metric; Part Description 10uF 10% or 20% 35V Ceramic Capacitor X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; LCSC C440198
C9: 1.2nF; C_0603_1608Metric; Part Description 1200pF 10% 10V Ceramic Capacitor X5R 04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; LCSC C30615
C11: nf; C_0402_1005Metric
C16: nf; C_0402_1005Metric; Part Description 220 pF, 50 V, 0402 [1005 Metric], ± 5%,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
C33: 100n 100v; C_0805_2012Metric; Part Description 0.1uF 10% 100V Ceramic Capacitor X5R 04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; LCSC C28233
C38: 100uF; C_1206_3216Metric_Pad1.33x1.80mm_HandSolder; LCSC C15008
C39: 1uF; C_0603_1608Metric_Pad1.08x0.95mm_HandSolder; LCSC C15849
D2: MMBZ5242BLT3G; D_SOT-23_ANK; Part Description Zener Diode 12V 225mW 5% Surface Mount 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; LCSC C268585
D8: SMBJ33A; D_SMB; LCSC C353366
F2: Fuse; Fuse_Littelfuse-NANO2-451_453
IC2: BD2226G-TR; SOT95P280X125-5N; Manufacturer_Part_Number BD2226G-TR; Mouser Part Number 755-BD2226G-TR
J7: USB_A; USB_A_Wuerth_614004134726_Horizontal; Mouser No 710-614004134726
J8: Conn_01x02_Male; JST_XH_S2B-XH-A_1x02_P2.50mm_Horizontal
L1: SRN6045TA-3R3Y; L_Bourns_SRN6045TA; Part Description 3.3µH Semi-Shielded Wirewound Inductor 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
Q4: DMP3013SFV-7; Diodes_PowerDI3333-8; Part Description DMP3013SFV-7 - Power MOSFET, P Channel,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; LCSC C264098
R8, R9: 12K 1%; R_0402_1005Metric; Part Description Resistor 12K M1005 1% 63mW; LCSC C25752
R10: 20K 1%; R_0402_1005Metric; Part Description Resistor 20K M1005 1% 63mW; LCSC C25765
R11: 10R; R_0402_1005Metric; Part Description Resistor 10R M1005 1% 63mW; LCSC C25077
R12: 2.2K 1%; R_0402_1005Metric; Part Description Resistor 2.2K M1005 1% 63mW; LCSC C25879
TP1, TP2, TP3: TestPoint; TestPoint_Pad_D1.0mm
U3: AP64501SP-13; SOIC-8-1EP_3.9x4.9mm_P1.27mm_EP2.95x4.9mm_Mask2.71x3.4mm_Th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; Part Description Buck Switching Regulator IC Positive Ad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; LCSC C2071517

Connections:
/+12v: F2.1; also elsewhere on the board
/PSU/P12V: C8.1, C10.1, C12.1, C14.1, C15.1, C17.1, C18.1, C19.1, D2.1 (K), Q4.1 (S), Q4.2 (S), Q4.3 (S), TP2.1, U3.2 (VIN)
/PSU/PSU_EN: U3.3 (EN); also elsewhere on the board
/PSU/USB_5v: IC2.5 (OUT), J7.1 (VBUS)
/Raspberry Pi/P5V_HAT: C2.1, C3.1, C4.1, C5.1, C6.1, C16.1, C38.1, C39.1, IC2.1 (IN), IC2.3 (EN), J8.2, L1.2, R9.1, TP3.1; also elsewhere on the board
GND: C2.2, C3.2, C4.2, C5.2, C6.2, C8.2, C9.2, C10.2, C11.2, C13.2, C14.2, C15.2, C17.2, C18.2, C19.2, C33.2, C38.2, C39.2, D8.2 (A2), IC2.2 (GND), IC2.4 (~OC), J7.4 (GND), J7.5 (Shield), J8.1, R8.2, R12.2, TP1.1, U3.7 (GND), U3.9 (EP); also elsewhere on the board
unnamed: C7.1, R11.2
unnamed: C7.2, U3.1 (BST)
unnamed: C9.1, R10.2
unnamed: C11.1, R10.1, U3.6 (COMP)
unnamed: C12.2, D2.2 (A), Q4.4 (G), R8.1
unnamed: C13.1, U3.4 (SS)
unnamed: C16.2, R9.2, R12.1, U3.5 (FB)
unnamed: C33.1, D8.1 (A1), F2.2, Q4.5 (D)
unnamed: L1.1, R11.1, U3.8 (SW)

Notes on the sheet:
BD2226G-TR C308587
SSD Power Out
USB Power Out
+5v @ 3A PSU ( 7.5v-28v Input )
Reverse polarity protection
Ideal diode to prevent reverse polarity at the input
5v @ 3A PSU
Buck converter

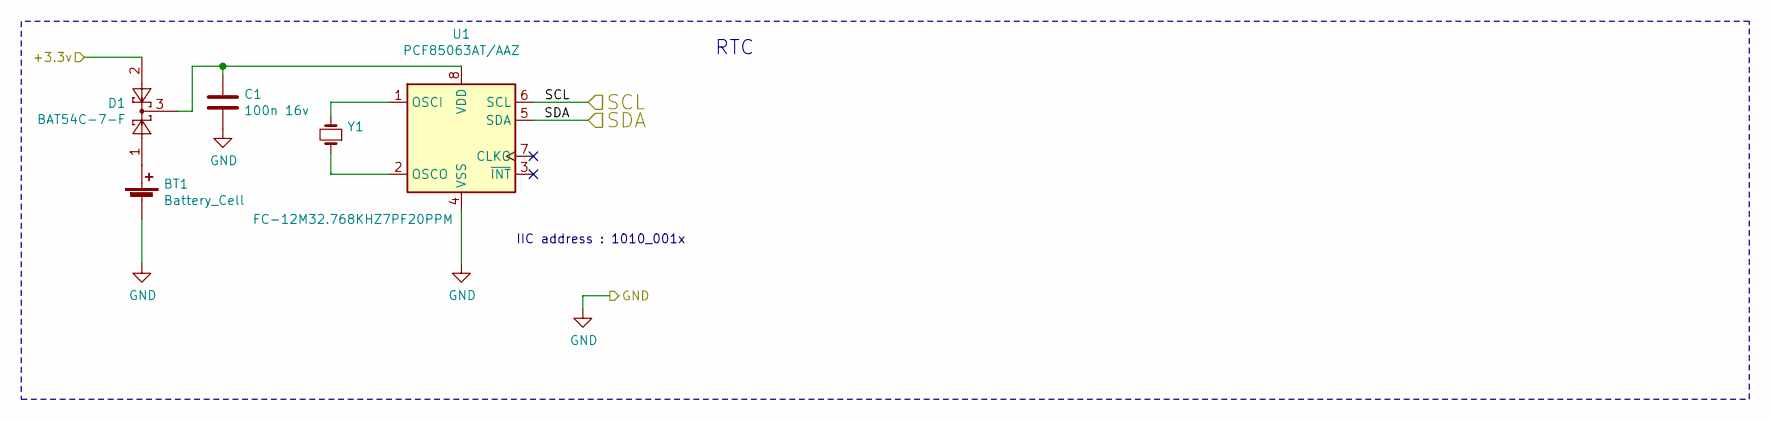
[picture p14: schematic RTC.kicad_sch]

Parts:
BT1: Battery_Cell; BatteryHolder_Keystone_3034_1x20mm; Part Description Battery Retainer Coin, 20.0mm 1 Cell SM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; Mouser No 534-3034
C1: 100n 16v; C_0402_1005Metric; Part Description 0.1uF 10% 16V Ceramic Capacitor X7R 040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; LCSC C1525
D1: BAT54C-7-F; SOT-23; Part Description Diode Array 1 Pair Common Cathode Schot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; LCSC C37704
U1: PCF85063AT/AAZ; SOIC-8_3.9x4.9mm_P1.27mm; Part Description Real Time Clock (RTC) IC Clock/Calendar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; LCSC C7440
Y1: FC-12M32.768KHZ7PF20PPM; Crystal_SMD_3215-2Pin_3.2x1.5mm; Part Description Crystal 32.768KHz 7pF 20pmm; LCSC C99009

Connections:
/+3.3v: D1.2; also elsewhere on the board
/RTC Clock/SCL: U1.6 (SCL); also elsewhere on the board
/RTC Clock/SDA: U1.5 (SDA); also elsewhere on the board
GND: BT1.2 (-), C1.2, U1.4 (VSS); also elsewhere on the board
unnamed: BT1.1 (+), D1.1
unnamed: C1.1, D1.3, U1.8 (VDD)
unnamed: U1.1 (OSCI), Y1.2
unnamed: U1.2 (OSCO), Y1.1

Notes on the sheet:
RTC
IIC address : 1010_001x

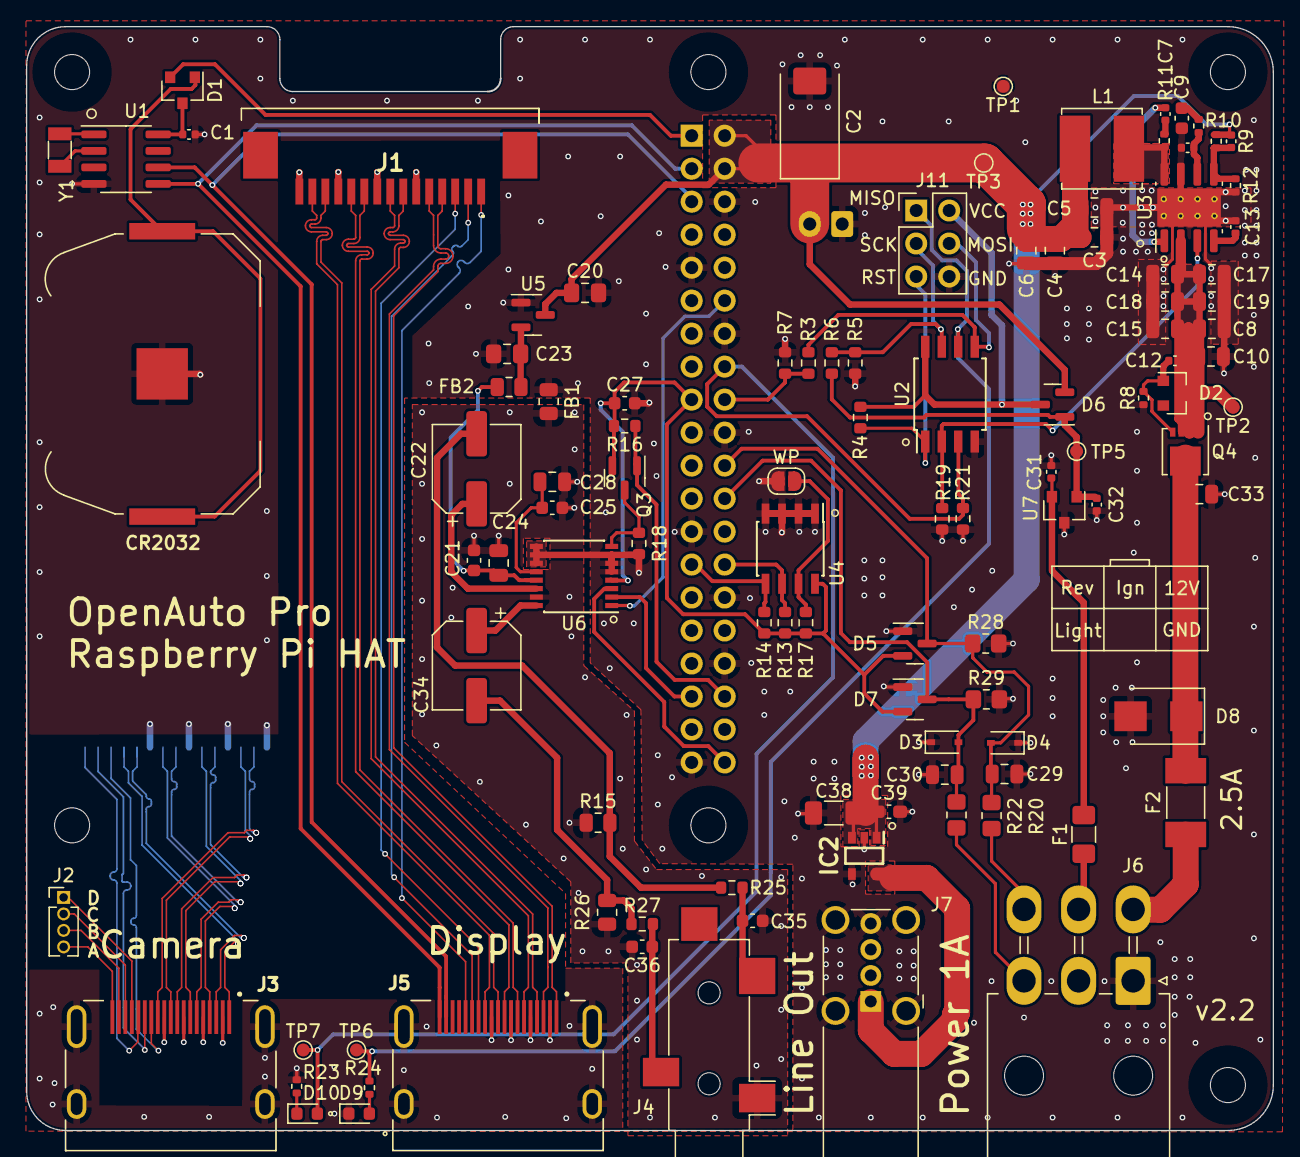
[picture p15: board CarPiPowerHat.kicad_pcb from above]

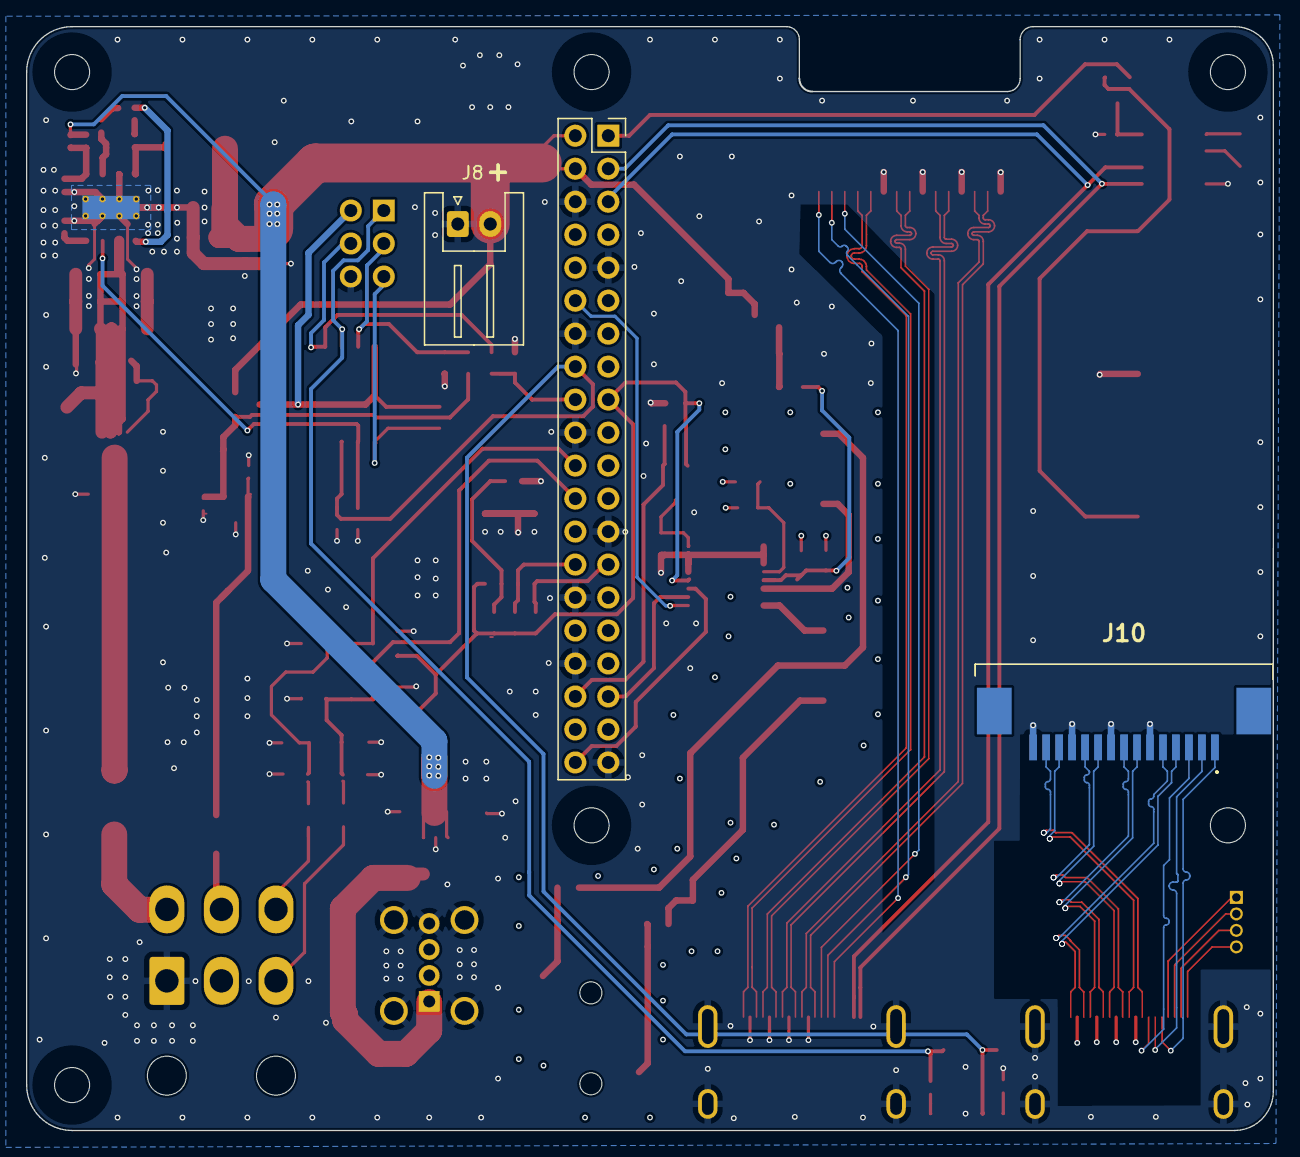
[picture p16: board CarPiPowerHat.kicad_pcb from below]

Board: 4 copper layers, 96.0 x 85.0 mm, 115 parts (3 on the bottom side), 82 nets.

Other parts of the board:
C30: 22nF; C_0805_2012Metric
D3: PESD12VL1BA-N; D_SOD-323
D7: BAT54S; SOT-23
J3: HDMI_A_1.4; EDAC 690-019-298-412
J10: 1-84953-5; 1849535
R22: 10k; R_0805_2012Metric_Pad1.20x1.40mm_HandSolder
R29: 1M; R_0805_2012Metric_Pad1.20x1.40mm_HandSolder

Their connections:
/+3.3v: D7.2; also elsewhere on the board
/HDMI Connector Camera/A: J3.19 (HPD/HEAC-); also elsewhere on the board
/HDMI Connector Camera/B: J3.18 (+5V); also elsewhere on the board
/HDMI Connector Camera/C: J3.17 (GND); also elsewhere on the board
/HDMI Connector Camera/CEC: J3.13 (CEC), J10.3
/HDMI Connector Camera/CK+: J3.10 (CK+), J10.13
/HDMI Connector Camera/CK-: J3.12 (CK-), J10.14
/HDMI Connector Camera/C_SCL: J3.15 (SCL), J10.1
/HDMI Connector Camera/D: J3.16 (SDA); also elsewhere on the board
/HDMI Connector Camera/D0+: J3.7 (D0+), J10.10
/HDMI Connector Camera/D0-: J3.9 (D0-), J10.11
/HDMI Connector Camera/D1+: J3.6 (D1-), J10.8
/HDMI Connector Camera/D1-: J3.4 (D1+), J10.7
/HDMI Connector Camera/D2+: J3.1 (D2+), J10.4
/HDMI Connector Camera/D2-: J3.3 (D2-), J10.5
/HDMI Connector Camera/UTILITY/HEAC+: J3.14 (UTILITY/HEAC+), J10.2
/Light Input/OUT: C30.1, D3.2 (A2), D7.3, R22.1, R29.1; also elsewhere on the board
CAR_LIGHT: R22.2; also elsewhere on the board
GND: C30.2, D3.1 (A1), D7.1, J3.2 (D2S), J3.5 (D1S), J3.8 (D0S), J3.11 (CKS), J3.SH1 (SH), J3.SH2 (SH), J3.SH3 (SH), J3.SH4 (SH), J10.6, J10.9, J10.12, J10.15, R29.2; also elsewhere on the board

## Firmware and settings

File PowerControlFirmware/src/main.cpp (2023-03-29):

#include <Arduino.h>
#include <avr/io.h>
#include <util/delay.h>
#include <Bounce2.h>

#define PIN_LED PB1                                                            // Pin to LED
#define PIN_POWER_CNTRL PB3                                                    // Pin to enable / disable power to Pi
#define PIN_IGN_SENSE PB2                                                      // Pin to sense ignition
#define PIN_PI_IN PB4                                                          // Pin from Pi to tell it is up and running
#define PIN_PI_OUT PB0                                                         // Pin to Pi to tell it to shut down
#define PULSE_DURATION_SLOW 150
#define PULSE_DURATION_FAST 30
#define PULSE_DURATION_SUPER_FAST 20
#define WAITTIME_FOR_PI_TO_RESPOND 6000
#define FINAL_WAIT_TIME 500

enum State {
  WAIT_FOR_PI_BOOT,
  RUNNING,
  WAIT_FOR_PI_SHUTDOWN,
  WAIT_FOR_PI_COME_BACK,
  SHUTDOWN,
  KILL,
};

State g_currentState = WAIT_FOR_PI_BOOT;
unsigned long g_eventStartMillis = 0L;
Bounce g_ignSense = Bounce();                                                  // Instantiate a Bounce object

// pin states
int g_ignitionOn = true;
int g_piOn = false;

void pulseLed(int speed) {
  analogWrite(PIN_LED, sin( 2 * PI / speed * (millis() - g_eventStartMillis) + 3 * PI / 2) * 128 + 128);
}

void setup() {
  pinMode(PIN_PI_IN, INPUT);
  pinMode(PIN_LED, OUTPUT);

  pinMode(PIN_POWER_CNTRL, OUTPUT);
  digitalWrite(PIN_POWER_CNTRL, 1);

  pinMode(PIN_PI_OUT, OUTPUT);
  digitalWrite(PIN_PI_OUT, 0);

  g_ignSense.attach(PIN_IGN_SENSE, INPUT);                                     // Attach the debouncer to a pin with INPUT_PULLUP mode
  g_ignSense.interval(150);                                                    // Use a debounce interval of 150 milliseconds
}

void switchState(State newState) {
  g_eventStartMillis = millis();                                               // Reset timeout timer
  g_currentState = newState;                                                   // Set new state
}

void loop() {
  if (g_ignSense.changed()) {                                                  // Get current pin states
    g_ignitionOn = g_ignSense.read();
  }
  g_piOn = digitalRead(PIN_PI_IN);

  switch(g_currentState) {
    case WAIT_FOR_PI_BOOT:
      pulseLed(PULSE_DURATION_SLOW);

      if (g_piOn) {                                                             // Pi signals it has booted
        switchState(RUNNING);
        return;
      }

      if(millis() - g_eventStartMillis > WAITTIME_FOR_PI_TO_RESPOND) {          // Timeout Pi did not shut down in time, cut power anyways
        switchState(SHUTDOWN);
        return;
      }

      break;
    case RUNNING:
      analogWrite(PIN_LED, 255);

      if (g_ignitionOn == false) {                                              // Ignition is switched off shutdown pi
        digitalWrite(PIN_PI_OUT, 1);                                            // Tell pi to shut down
        switchState(WAIT_FOR_PI_SHUTDOWN);
        return;
      }

      if (g_piOn == false) {                                                    // Pi was switched off, but ignition is still on
        switchState(WAIT_FOR_PI_COME_BACK);
        return;
      }

      break;
    case WAIT_FOR_PI_COME_BACK:                                                 // Ignition is on, but pi shut down - maybe a reboot?
      pulseLed(PULSE_DURATION_SUPER_FAST);

      if(g_piOn) {                                                              // Pi did come back online back to running
        switchState(RUNNING);
        return;
      }

      if(millis() - g_eventStartMillis > WAITTIME_FOR_PI_TO_RESPOND) {         // Timeout Pi did not come back, cut power
        switchState(SHUTDOWN);
        return;
      }

      break;
    case WAIT_FOR_PI_SHUTDOWN:                                                  // We told the pi to shut down, now we wait for shutdown
      pulseLed(PULSE_DURATION_FAST);

      if (g_piOn == false) {                                                    // Pi did shut down, cut power
        switchState(SHUTDOWN);
        return;
      }

      if(millis() - g_eventStartMillis > WAITTIME_FOR_PI_TO_RESPOND) {         // Timeout Pi did not shut down in time, cut power anyways
        switchState(SHUTDOWN);
        return;
      }

      break;
    case SHUTDOWN:
      analogWrite(PIN_LED, 25);

      if(millis() - g_eventStartMillis > FINAL_WAIT_TIME) {                    // Final wait time to make sure everything shut down
        switchState(KILL);
        return;
      }

      break;
    case KILL:
      digitalWrite(PIN_LED, 0);
      digitalWrite(PIN_POWER_CNTRL, 0);                                        // Shut down the power circuit

      // Usually shutting down the power circuit will shut down the attiny as well and the program ends here
      // It might happen, that the user restarts the engine during this time. If so, we want to
      // enable the power circuitry again after a clean shutdown
      delay(100);
      if (g_ignitionOn == true) {
        digitalWrite(PIN_POWER_CNTRL, 1);                                    // Enable the power circuit
        digitalWrite(PIN_PI_OUT, 0);
        switchState(WAIT_FOR_PI_BOOT);
      }

      break;
  }
  g_ignSense.update();                                                         // Update the Bounce instance
}

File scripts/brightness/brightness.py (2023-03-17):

"""
Backlight Control Script With TSL2561 Light Sensor

This script implements a recommendation from analog devices
https://www.analog.com/en/design-notes/a-simple-implementation-of-lcd-brightness-control-using-the-max44009-ambientlight-sensor.html
"""

import math
import time
from multiprocessing import Process, Value
import sys
import signal
import RPi.GPIO as GPIO
import logging
import argparse
from tsl2561 import *
from statistics import mean
from yaml import load
try:
    from yaml import CLoader as Loader
except ImportError:
    from yaml import Loader

formatter = logging.Formatter(fmt="%(asctime)s %(levelname)s: %(message)s", datefmt="%Y.%m.%d %H:%M:%S")
logger = logging.getLogger(__name__)
handler = logging.StreamHandler(stream=sys.stdout)
handler.setFormatter(formatter)
logger.addHandler(handler)

# Configuration
with open("config.yml", "r") as ymlfile:
    cfg = load(ymlfile, Loader=Loader)

NIGHT_MODE_GPIO_PIN = cfg["night_mode_gpio_pin"]
LUX_SAMPLE_COUNT = cfg["lux_sample_count"]
NIGHT_MODE_ON_LUX = cfg["night_mode_on_lux"]
NIGHT_MODE_OFF_LUX = cfg["night_mode_off_lux"]
MAXIMUM_LUX_BREAKPOINT = cfg["maximum_lux_breakpoint"]
BRIGHTNESS_LEVEL_MIN = cfg["brightness_level_min"]
BRIGHTNESS_LEVEL_MAX = cfg["brightness_level_max"]

# private
current_lux = Value('i', 1)
current_brightness_percent = 0.5
desired_brightness_percent = 0.5
running = True
step_size = 0.01

def map_range(x, in_min, in_max, out_min, out_max):
    """Maps an value to a target range

    Args:
        x (_type_): The value to map
        in_min (_type_): Input minimum
        in_max (_type_): Input maximum
        out_min (_type_): Output minimum
        out_max (_type_): Output maximum

    Returns:
        _type_: The mapped value
    """
    return (x - in_min) * (out_max - out_min) / (in_max - in_min) + out_min

def get_brightness_percent_from_lux_reading(lux) -> float:
    """calculate screen brightness in percent for given lux

    Args:
        lux (int): The current light reading in lux

    Returns:
        float: The brightness in percent based on a function
    """
    if lux > MAXIMUM_LUX_BREAKPOINT:
        return 1.0
    if lux == 0:
        return 0
    else:
        return (9.9323 * math.log(lux) + 27.059) / 100.0;

def process_read_sensor(tsl_sensor, curr) -> None:
    """
    Reads the sensor and calculates the average of the last readings
    """
    global running

    lux_readings = []

    while running:
        try:
            # Reading the value does a time.sleep
            lux = tsl_sensor.lux()

            lux_readings.append(lux)
            if len(lux_readings) > LUX_SAMPLE_COUNT:
                lux_readings.pop(0)

            curr.value = int(mean(lux_readings))
            logger.info(f"lux reading: {lux}, avg: {curr.value}")
            time.sleep(0.5)
        except KeyboardInterrupt:
            break

def step_brightness() -> None:
    """Steps the brightness from current value to desired value
    """
    global current_brightness_percent, desired_brightness_percent, step_size

    if current_brightness_percent == desired_brightness_percent:
        return
    
    if current_brightness_percent > desired_brightness_percent:
        if (current_brightness_percent-step_size) < desired_brightness_percent:
            current_brightness_percent = desired_brightness_percent
        else:
            current_brightness_percent = current_brightness_percent - step_size
    elif current_brightness_percent < desired_brightness_percent:
        if (current_brightness_percent+step_size) > desired_brightness_percent:
            current_brightness_percent = desired_brightness_percent
        else:
            current_brightness_percent = current_brightness_percent + step_size

    set_brightness(current_brightness_percent)

def set_brightness(brightness_in_percent) -> None:
    """Sets the display brightness
    Calculates the correct value from percent value
    Args:
        brightness_in_percent (float): Brightness in percent
    """
    brightness = int(map_range(brightness_in_percent, 0.0, 1.0, BRIGHTNESS_LEVEL_MIN, BRIGHTNESS_LEVEL_MAX))
    logger.debug("brightness in percent: %s, brightness to set: %s", brightness_in_percent, brightness)
    try:
        with open("/sys/class/backlight/rpi_backlight/brightness", "w") as f:
            f.write(str(brightness))
            f.flush()
    except OSError as e:
        print(f"Unable to open brightness file: {e}", file=sys.stderr)
        return
    except Exception:
        logger.exception('Could not set brightness')

def set_day_night_mode(lux):
    """Sets the day/night mode via GPIO port

    Args:
        lux (int): Current light reading in lux
    """
    GPIO.setup(NIGHT_MODE_GPIO_PIN, GPIO.IN)
    current_state = GPIO.input(NIGHT_MODE_GPIO_PIN) 

    GPIO.setup(NIGHT_MODE_GPIO_PIN, GPIO.OUT)
    # Setting up GPIO
    if lux < NIGHT_MODE_ON_LUX and current_state == False:
        GPIO.output(NIGHT_MODE_GPIO_PIN, True)                       # set "Night mode"
        logger.info("Setting night mode")
    if lux > NIGHT_MODE_OFF_LUX and current_state:
        GPIO.output(NIGHT_MODE_GPIO_PIN, False)                       # set "Night mode" false
        logger.info("Setting day mode")
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

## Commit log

2021-03-07 added jtag
    [CarPiPowerHat.kicad_sch]
2021-03-17 Added first firmware version
    [CarPiPowerHat.kicad_pcb, CarPiPowerHat.kicad_sch, hdmi_connectors.kicad_sch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]
2021-03-18 added connectors
    [CarPiPowerHat.kicad_pcb, CarPiPowerHat.kicad_sch, hdmi_connectors.kicad_sch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]
2021-03-25 doing some traces
    [CarPiPowerHat.kicad_pcb, CarPiPowerHat.kicad_sch, RTC.kicad_sch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]
2021-04-01 Everything routed, DRC ok
    [CarPiPowerHat.kicad_pcb, CarPiPowerHat.kicad_sch, i2s_dac.kicad_sch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]
2021-04-10 Repositioning of connectors
    [CarPiPowerHat.kicad_pcb, raspberry.kicad_sch]
2021-06-24 updated layout
    [CarPiPowerHat.kicad_pcb, CarPiPowerHat.kicad_sch, RTC.kicad_sch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]
2021-07-19 added some more documentation
    [CarPiPowerHat.kicad_pcb, CarPiPowerHat.kicad_sch, RTC.kicad_sch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]
2021-07-30 Removed TVS diodes for now, fixed DRC issues
    [CarPiPowerHat.kicad_pcb, CarPiPowerHat.kicad_sch, power_control.kicad_sch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]
2021-08-23 Finished Layout
    [CarPiPowerHat.csv, CarPiPowerHat.kicad_pcb, CarPiPowerHat.kicad_sch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]
2021-08-25 Added part numbers
    * Selected parts from lcsc
    * Checked footprints
    [CarPiPowerHat.kicad_pcb, CarPiPowerHat.kicad_sch, RTC.kicad_sch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]
2021-09-16 try to fix error in control software
    [main.cpp]
2021-10-01 Fixed some bugs, not done yet
    [CarPiPowerHat-B_Cu.gbr, CarPiPowerHat-B_Mask.gbr, CarPiPowerHat-B_Silkscreen.gbr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]
2021-10-01 removed unnecessary reverse polarity protection
    [CarPiPowerHat.kicad_pcb, CarPiPowerHat.kicad_sch, input_pin_protect.kicad_sch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]
2021-10-02 Some rerouting
    [CarPiPowerHat.kicad_pcb, CarPiPowerHat.kicad_sch, hdmi_connectors.kicad_sch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]
2021-10-03 Finalized 2.2
    [CarPiPowerHat.kicad_pcb, CarPiPowerHat.kicad_sch, hdmi_connectors.kicad_sch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]
2021-10-04 Finalizing, checking parts
    Might be ready for production
    [CarPiPowerHat.kicad_pcb, CarPiPowerHat.kicad_sch, RTC.kicad_sch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]
2021-11-04 Working power control firmware
2021-11-23 Moved HDMI ports
    The HDMI ports were offset by 1-2 mm
    [CarPiPowerHat-B_Cu.gbl, CarPiPowerHat-B_Cu.gbr, CarPiPowerHat-B_Mask.gbs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]
2022-01-29 Some bugfixing, added cam.py script
    [CarPiPowerHat.kicad_pcb, CarPiPowerHat.kicad_sch, RTC.kicad_sch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]
2022-02-04 Updated schematic
    [CarPiPowerHat.kicad_pcb]
2022-10-13 fix: fixed some minor inconveniences
    [brightness.py, main.cpp]
2023-03-29 fix: Update brightness service fix: Update rearcamera requirements.txt
    [main.cpp]
